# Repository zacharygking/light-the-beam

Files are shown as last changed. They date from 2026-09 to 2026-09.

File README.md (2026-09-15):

# Light the Beam

A 3D-printed Golden 1 Center that lights its purple beam when the Sacramento Kings win, with a live scoreboard in the base.



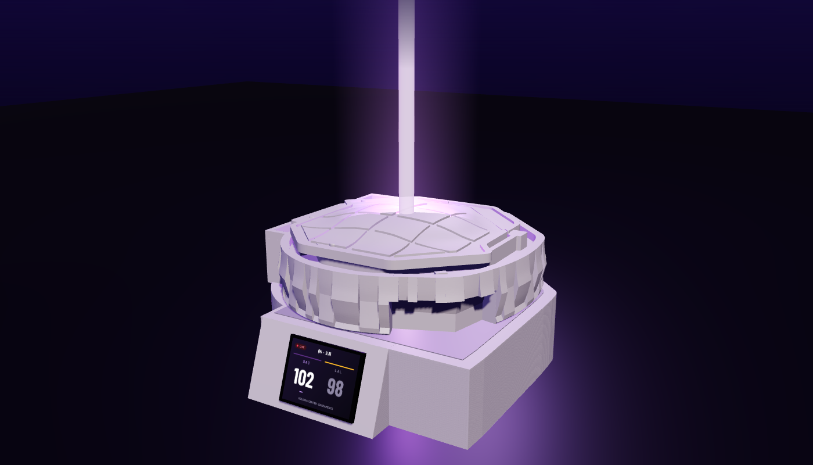
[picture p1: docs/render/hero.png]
The finished piece: the arena on its plinth, purple beam rising, live score on the screen


The arena base is [Dave Lack's free Printables model](https://www.printables.com/model/338758-golden-1-center-light-the-beam), printed unmodified (the lid gets one hole). Everything else is this repo: a printed plinth with a sloped console that holds a 2.8" ESP32 touch display, a 14-LED beam in a single-wall diffuser tube, firmware that reads ESPN's public scores over WiFi, and the documents to build it without soldering.

## What it does

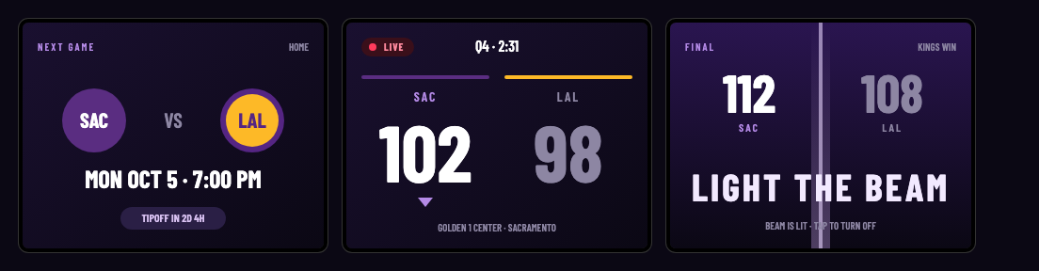
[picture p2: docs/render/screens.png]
The three screens: next game with logos and countdown, live score with clock, and the final screen that says Light the Beam


| | |
|---|---|
| **Next game** | Opponent logo, home or away, tipoff in Pacific time, countdown. Polled every 10 minutes, every 30 seconds near tipoff. |
| **Live** | Score, quarter and clock every 20 seconds. Leader in white, trailer in grey. Halftime and overtime are labelled; scores animate when they change. |
| **Final** | If the Kings win, the beam rises from the base like the real one and holds purple for up to 12 hours. |
| **Touch** | Tap to light the beam yourself. Hold for a second to step brightness. |
| **Setup** | First boot opens a `KingsBeam-Setup` WiFi network; join it from a phone and pick your home WiFi. Nothing is typed into code. |
| **Night** | Screen dims 11 pm to 7 am and whenever the room is dark. |

## How it's built

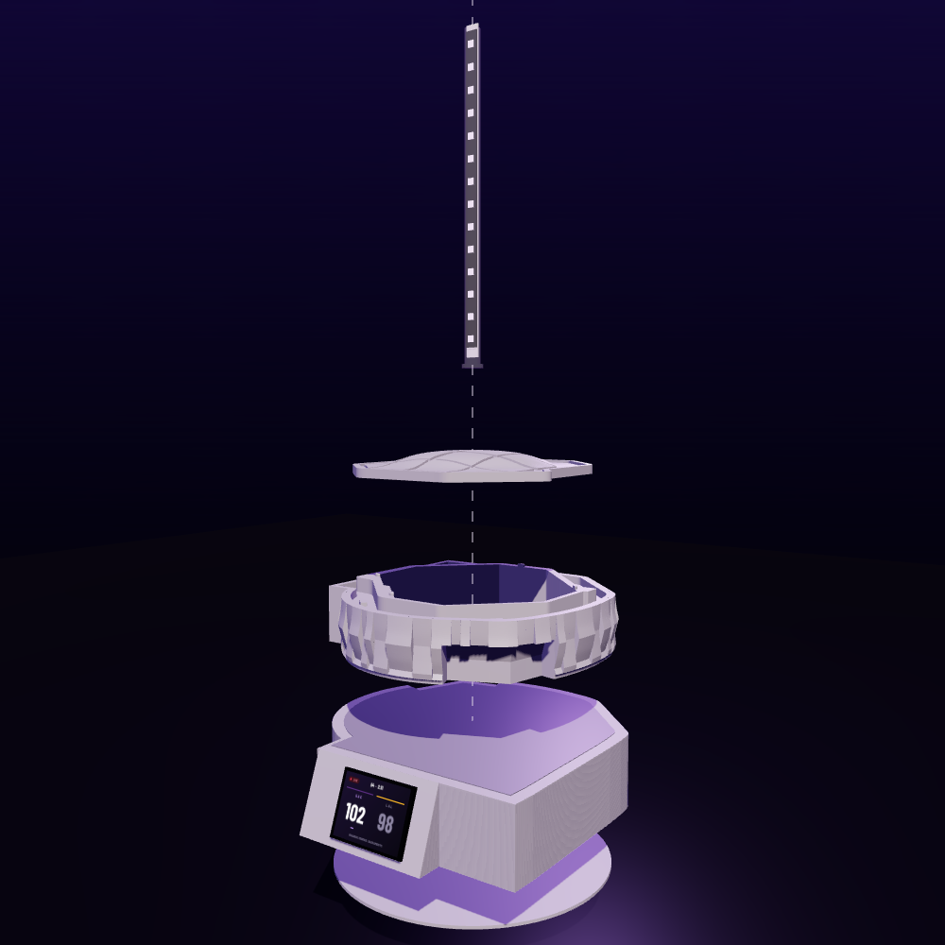
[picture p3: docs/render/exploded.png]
Exploded view: beam tube with the strip on its spine, arena lid, arena base with the tube socket, plinth with the display board, bottom lid


- **Plinth** ([`models/plinth.scad`](models/plinth.scad)): a 56 mm stand that follows the arena's measured footprint, with a console on the front whose face leans back 20° so the screen points at you at a desk. Three parts, each printable without supports: a wall ring with the console, a flat top plate whose recess is cut to the footprint (so the arena only fits one way) with a slot under the arena's own wire channel, and a bottom lid. The board slides up into the console with its USB plug attached; the lid closes the pocket.
- **Beam** ([`models/beam_tube.scad`](models/beam_tube.scad), [`models/strip_holder.scad`](models/strip_holder.scad)): a 250 mm tube printed in vase mode from white PLA, with the WS2812B strip on a printed spine inside and a socket glued in the arena's well.
- **Board**: ESP32-2432S028R, the "Cheap Yellow Display". Three lever-nut connections to the strip: 5 V, ground, data on GPIO 22.
- **Firmware** ([`firmware/`](firmware/)): PlatformIO, Arduino framework. LVGL 9 UI with Barlow Condensed fonts and all 30 team logos baked in, FastLED for the beam, WiFiManager for the captive portal, ArduinoJson with a filter for the 21 KB ESPN response. A `cyd_demo` build cycles the three screens without WiFi.

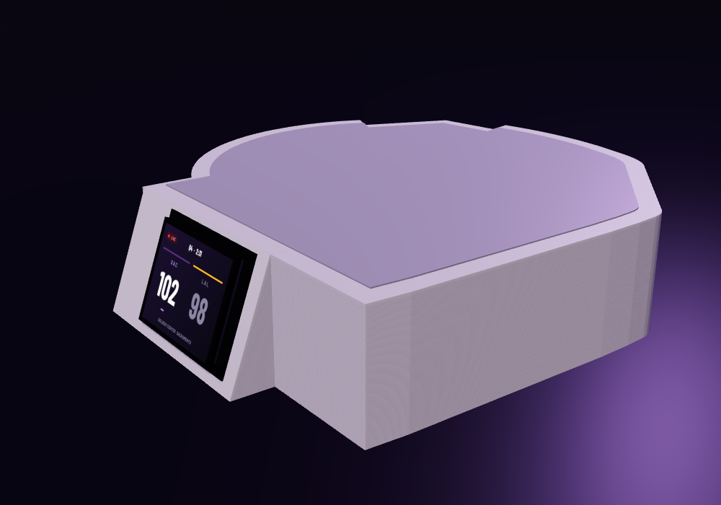
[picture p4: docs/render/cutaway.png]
Cutaway of the plinth: the display board leaning back in the console, lever nuts inside


## Documents

| | |
|---|---|
| [**Build guide** (PDF)](docs/kings-beam-assembly.pdf) | 15 pages, 22 steps with diagrams: print, flash, beam, arena and plinth, WiFi setup, troubleshooting. |
| [**Overview** (PDF)](docs/kings-beam-overview.pdf) | What it is and how it works, in five pages. |
| [**Shopping list** (PDF)](docs/kings-beam-shopping-list.pdf) · [HTML](docs/shopping-list.html) | Four hardware items in one Amazon cart link, filament, free downloads, local pickup in San Francisco. |
| [**Bill of materials**](docs/bom.md) | Sourcing notes, alternatives, prices with tax, wiring table. |

Hardware is about **$41 with tax**, everything bought new; filament is separate.

## Building it yourself

```sh
# Firmware (PlatformIO; `pip3 install --user platformio` if you don't have it)
cd firmware
pio test -e native                 # parser tests against captured ESPN responses
pio run -e cyd_demo -t upload      # demo build first: cycles NEXT → LIVE → FINAL, no WiFi
pio run -e cyd -t upload           # the real thing
pio device monitor -b 115200

# Models (OpenSCAD 2021.01 or newer)
python3 tools/measure_arena.py     # reads the downloaded arena STL, writes the footprint outline
cd models && make                  # exports plinth, lid, console test part, tube, spine, socket

# Everything at once
tools/validate.sh                  # tests, both firmware builds, exports, PDFs, link check
```

Print the console test part (`plinth_test.stl`, about 40 minutes) before the full plinth to confirm the board fit. The [build guide](docs/kings-beam-assembly.pdf) has the rest.

## Repository

| Path | What |
|---|---|
| `firmware/` | PlatformIO project: `src/` (UI, beam, touch, network, parser), `include/lv_conf.h`, `test/` (native Unity tests + real ESPN fixtures) |
| `models/` | OpenSCAD sources, `exports/` STLs, `printables/` for the downloaded arena files, `arena_outline.scad` (measured footprint) |
| `tools/` | `espn_probe.py`, `make_fixtures.py`, `check_fixtures.py`, `make_fonts.py` (TTF → LVGL, no Node needed), `make_logos.py`, `measure_arena.py`, `render_views.sh`, `validate.sh` |
| `docs/` | Guides and BOM, `render/` (three.js scene that renders every view through headless Chrome) |
| `.github/workflows/ci.yml` | Native tests, both ESP32 builds, generator reproducibility, OpenSCAD export |

## Notes from building it

- **ESPN's edge returns 403 to browser-looking user agents from non-browser clients.** The stock `ESP32HTTPClient` and `python-urllib` user agents pass. The firmware never spoofs a browser.
- ESPN's document nests 14 levels deep; ArduinoJson's default limit is 10. With a filter, ArduinoJson also reports success on non-JSON input, so the parser checks for the team object explicitly.
- The team endpoint omits opponent colours for upcoming games, so team colours ship with the logos.
- Fonts are converted from TTF to LVGL's bitmap format with a 150-line Python script, which keeps Node out of the toolchain.
- The renders are a three.js scene rasterised by headless Chrome's software WebGL. Once the Printables STL was downloaded, the scene loads the real mesh, and the same slicer measured the arena for the plinth.

## Status

Firmware builds and the parser is tested against real responses, but nothing has run on hardware yet. The three things most likely to need a tweak on first flash are display rotation, the touch pressure threshold, and the first LED's data level. The preseason opener is October 5, 2026 (LAL @ SAC); the live and final screens get their first real data then.

## Live win probability (v2, on the bench)

A four-coefficient logistic model of the home team's chance to win from the score, clock and period, the fields the firmware already polls, so it adds no requests. It was fitted on every play of the 2024-25 season and evaluated on every play of 2025-26, with ESPN's own in-game win probability recorded on the same plays as the benchmark:

| | Brier (lower is better) | log loss |
|---|---|---|
| this model | 0.162 | 0.476 |
| ESPN | 0.147 | 0.442 |
| home-court prior only | 0.247 | 0.687 |

The gap to ESPN is pregame information (team strength, possession): three Brier points in the first quarter, one thousandth by the fourth. Accuracy is 0.747 against ESPN's 0.778, but calibration is the number that matters for a probability pill, and league-wide it holds within three points in every bin. Restricted to Kings games it does not: the pill would have overstated a 22-win team's chances in toss-up situations, which is the case for adding a team-strength prior. Details, tables and open evaluation questions are in [docs/winprob.md](docs/winprob.md).

**The board trains itself.** The training plays are binned to 35,221 (margin, 5-second) cells with win/loss counts, a 247 KB table embedded in the firmware image. On boot the ESP32 refits the model from that table with `firmware/src/winprob_train.h`, a header-only Newton-Raphson trainer, and shows "TRAINED ON 623,853 PLAYS IN … MS" on the splash screen. It takes 23 ms on a laptop; the board's single-precision FPU should land well under a second.

**The bench is C++.** `firmware/src/winprob.h` is the exact function the ESP32 runs, and `pio test -e native` checks it against the Python trainer on 300 sampled plays, checks its shape (symmetry, monotonicity, end points), replays all 641,199 held-out plays through it asserting the Brier, fourth-quarter and calibration numbers above, and refits with the on-device trainer to confirm it reproduces the Python coefficients. It runs in CI. Data comes from `tools/fetch_pbp.py` (see [data/README.md](data/README.md)); `tools/train_winprob.py` refreshes the table, header, fixtures and report. Not wired to the live screen yet; that is a pill under the score once the hardware is up.

## Credits

Arena model by [Dave Lack](https://www.printables.com/@DaveLack_475585) on Printables. Scores from ESPN's public API. Team logos are NBA/ESPN property, embedded for personal use. Barlow Condensed by Jeremy Tribby, SIL Open Font License. Built with [PlatformIO](https://platformio.org), [LVGL](https://lvgl.io), [FastLED](https://fastled.io), [ArduinoJson](https://arduinojson.org), [WiFiManager](https://github.com/tzapu/WiFiManager), [OpenSCAD](https://openscad.org) and [three.js](https://threejs.org).

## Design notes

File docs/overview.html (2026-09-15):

Sacramento Kings · Golden 1 Center · Desk model

Render of the finished piece: the arena on its plinth, purple beam rising, live score on the screen

# LIGHT THE BEAM

A printed Golden 1 Center that lights its purple beam when the Kings win, with a live scoreboard in the base. WiFi, one USB cable, no soldering.

226 mmacross, on a Bambu P1S

2.8″ colortouch screen, LVGL UI

14 LEDsWS2812B beam, 250 mm tall

≈ $41hardware, tax in, new

Light the Beam · overviewSeptember 2026

What it does

## Features

### Next game, always up

Opponent logo, home or away, tipoff in Pacific time, and a countdown. Pulled from ESPN's public schedule; no account or API key.

### Live score and clock

Score, quarter and game clock refresh every 20 seconds during the game. The leader is drawn in white; the trailer fades to grey. Scores animate when they change.

### The beam lights itself on a win

When the final goes Kings, purple climbs the tube from the base, like the real one, then holds. It goes dark again before the next game.

### Light it yourself

Tap the screen to turn the beam on or off any time. Hold for a second to cycle brightness through three levels.

### Sleeps at night

The screen dims between 11 pm and 7 am, and whenever the board's light sensor sees a dark room.

### Phone WiFi setup

First boot puts up a "KingsBeam-Setup" network. Join it from a phone, pick your home WiFi, done. Nothing is typed into code.

### One cable, no soldering

A single USB charger powers the board and the beam. Three lever nuts join the strip to the board's pigtails.

### Stock arena, new plinth

Dave Lack's Printables arena base prints unmodified; the lid gets one 12.4 mm hole. A new printed plinth underneath holds the board, the screen window and the cable exit.

Light the Beam2

The 320 × 240 display

## Four screens

Next game. Logos on team-color discs, tipoff in local time, countdown pill. Polled every 10 minutes, every 30 seconds near tipoff.

Live. Pulsing pill, quarter and clock, team color bars, 84-pixel scores. Handles halftime, end of quarter and overtime.

Final, Kings win. A beam glow climbs the screen while the real one rises. On a loss: the score, "NEXT TIME", and a tap still lights it.

First boot. No credentials in code; the board runs a small setup page on its own network until it knows your WiFi.

Light the Beam3

Under the roof

## How it works

One request returns everything: the next event carries the date, opponent, status, score, clock and winner. The board only keeps the dozen fields it draws.

### Poll cadence

State | Every | Beam
Next game, far off | 10 min | off
Within 20 min of tipoff | 30 s | off
Live | 20 s | dim purple pulse
Final, Kings win | 5 min | rise, then hold up to 12 h
Final, loss | 5 min | off (tap still lights it)
ESPN unreachable | 60 s retry | unchanged, "offline" badge

### Things learned building it

ESPN's edge rejects browser-style user agents from non-browser clients with a 403, but accepts the ESP32 library's own default. The firmware never spoofs a browser.

The JSON nests fourteen levels deep. ArduinoJson's default limit is ten; the parser raises it and checks for the team object, since a filtered parse reports success on an HTML error page.

Fonts are converted from TTF to LVGL's bitmap format with a small Python script, so the build needs no Node toolchain.

Light the Beam4

Shopping and printing

## Parts and print list

Hardware | Price
ESP32-2432S028R 2.8″ touch display board (Amazon) | ~$14
WS2812B 5 V strip, 60/m, 1 m, IP30 (Amazon) | ~$9
5 V 2 A USB wall charger (Amazon or Best Buy) | ~$7
WAGO 221-413 lever nuts ×3 (Lowe's Bayshore or Amazon) | ~$8
SF sales tax 8.625 % | ~$3.30
Hardware total | ≈ $41

Optional: USB-C panel-mount jack for the back (~$9), level shifter if LED 1 flickers ($1.50). Prices are September 2026 estimates; links and local stores are in docs/bom.md.

Filament (P1S) | Price
Bambu PLA Basic Silver, 1 kg: arena, lid, plinth (~450 g) | $18.99
White PLA, any brand: beam tube, spine, socket (~35 g) | $13–19

Print | Settings | Time
Arena base, 220 mm | 0.2 mm, 3 walls, 15 %, no supports | ~9 h
Arena lid (no-hole, cut 12.4 mm) | 0.15 mm | ~2 h
Console test part | 0.2 mm | 40 min
Plinth ring, top plate, bottom lid | 0.2 mm, no supports | ~6 h
Beam tube, 254 mm | white, vase mode, 0 bottom layers | ~1 h
Spine + socket | any | 20 min

Exploded view: beam tube, arena lid, arena base, plinth, bottom lid

Top to bottom: beam tube with the strip on its spine, arena lid, arena base with the tube socket, plinth with the display board, press-fit bottom lid.

Light the Beam5

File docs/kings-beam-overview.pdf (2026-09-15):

SAC R A M ENTO K ING S · G O L D EN 1 C ENT E R · D E S K M O D E L

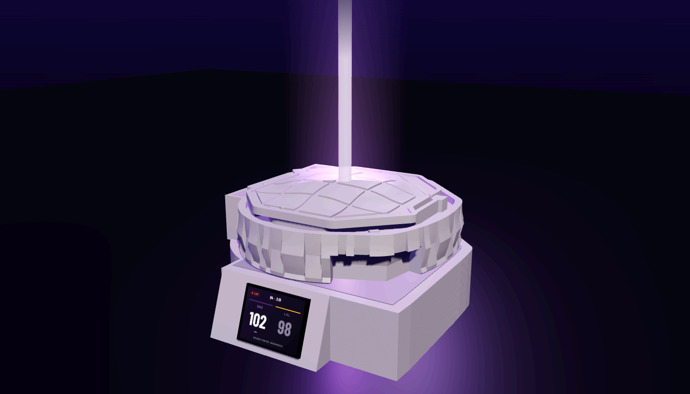
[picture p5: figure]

# LIGHT THE BEAM

## A printed Golden 1 Center that lights its purple beam when the

Kings win, with a live scoreboard in the base. WiFi, one USB cable, no soldering.

226 mm

across, on a Bambu P1S

# 2.8″ color

touch screen, LVGL UI

# 14 LEDs

WS2812B beam, 250 mm tall

≈ $41

hardware, tax in, new

Light the Beam · overview | September 2026

W H AT I T D O E S

# Features

## Next game, always up

Opponent logo, home or away, tipoff in Pacific time, and a countdown. Pulled from ESPN's public schedule; no account or API key.

## Live score and clock

Score, quarter and game clock refresh every 20 seconds during the game. The leader is drawn in white; the trailer fades to grey. Scores animate when they change.

## The beam lights itself on a win

When the final goes Kings, purple climbs the tube from the base, like the real one, then holds. It goes dark again before the next game.

## Light it yourself

Tap the screen to turn the beam on or off any time. Hold for a second to cycle brightness through three levels.

## Sleeps at night

The screen dims between 11 pm and 7 am, and whenever the board's light sensor sees a dark room.

## Phone WiFi setup

First boot puts up a "KingsBeam-Setup" network. Join it from a phone, pick your home WiFi, done. Nothing is typed into code.

## One cable, no soldering

A single USB charger powers the board and the beam. Three lever nuts join the strip to the board's pigtails.

## Stock arena, new plinth

Dave Lack's Printables arena base prints unmodified; the lid gets one 12.4 mm hole. A new printed plinth underneath holds the board, the screen window and the cable exit.

Light the Beam | 2

T H E 3 2 0 × 2 4 0 D I S P L AY

# Four screens

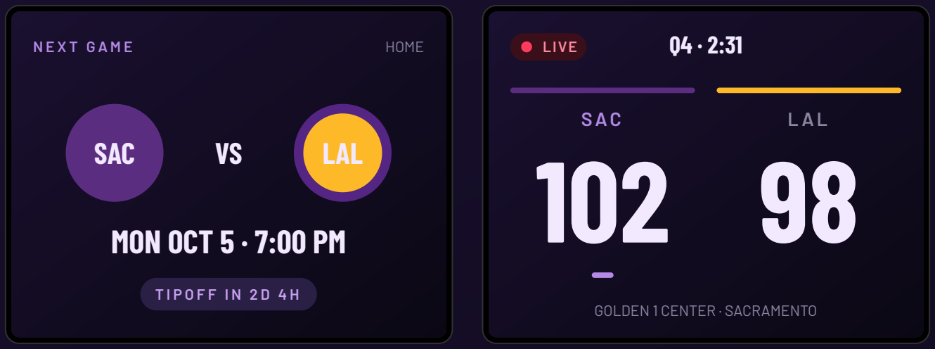
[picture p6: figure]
HOME; SAC; LAL; MON OCT 5 · 7:00 PM; LIVE; GOLDEN 1 CENTER · SACRAMENTO

Next game. Logos on team-color discs, tipoff in local time, countdown pill. Polled every 10 minutes, every 30 seconds near tipoff.

Live. Pulsing pill, quarter and clock, team color bars, 84-pixel scores. Handles halftime, end of quarter and overtime.

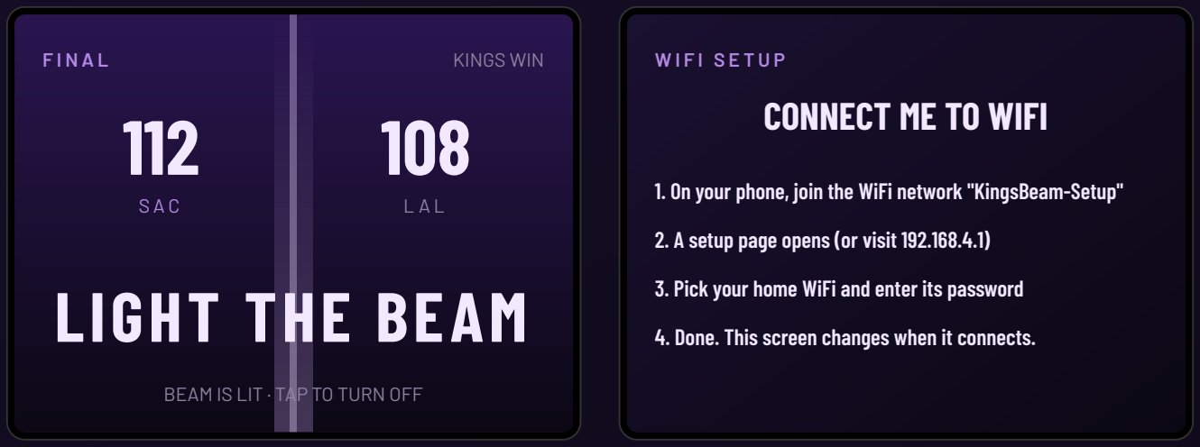
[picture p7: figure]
KINGS WIN; LIGHT THE BEAM; BEAM IS LIT · TAP TO TURN OFF; W I F I S E T U P CONNECT ME TO WIFI

Final, Kings win. A beam glow climbs the screen while the real one rises. On a loss: the score, "NEXT TIME", and a tap still lights it.

### 1. On your phone, join the WiFi network "KingsBeam-Setup"

### 2. A setup page opens (or visit 192.168.4.1)

### 3. Pick your home WiFi and enter its password

4. Done. This screen changes when it connects.

First boot. No credentials in code; the board runs a small setup page on its own network until it knows your WiFi.

UND E R T H E R O O F

# How it works

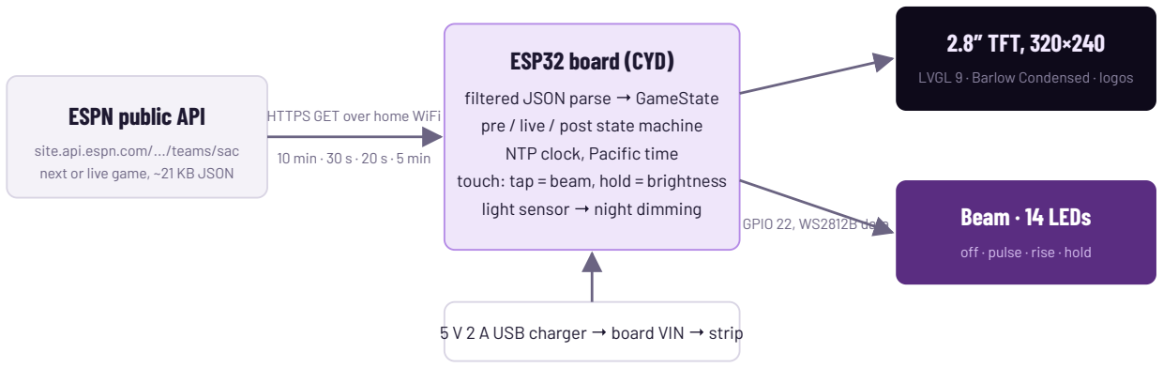
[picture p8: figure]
ESPN public API; site.api.espn.com/.../teams/sac next or live game, ~21 KB JSON; HTTPS GET over home WiFi; 10 min · 30 s · 20 s · 5 min; ESP32 board (CYD); filtered JSON parse → GameState pre / live / post state machine NTP clock, Pacific time touch: tap = beam, hold = brightness light sensor → night dimming; 2.8″ TFT, 320×240; LVGL 9 · Barlow Condensed · logos; GPIO 22, WS2812B data; Beam · 14 LEDs; off · pulse · rise · hold; 5 V 2 A USB charger → board VIN → strip

One request returns everything: the next event carries the date, opponent, status, score, clock and winner. The board only keeps the dozen fields it draws.

## Poll cadence

STATE | EVERY | BEAM
Next game, far off | 10 min | off
Within 20 min of tipoff | 30 s | off
Live | 20 s | dim purple pulse
Final, Kings win | 5 min | rise, then hold up to 12 h
Final, loss | 5 min | off (tap still lights it)
ESPN unreachable | 60 s retry | unchanged, "offline" badge

## Things learned building it

ESPN's edge rejects browser-style user agents from non-browser clients with a 403, but accepts the ESP32 library's own default. The firmware never spoofs a browser.

The JSON nests fourteen levels deep. ArduinoJson's default limit is ten; the parser raises it and checks for the team object, since a filtered parse reports success on an HTML error page.

Fonts are converted from TTF to LVGL's bitmap format with a small Python script, so the build needs no Node toolchain.

S H O P P ING AND P R INT ING

# Parts and print list

HARDWARE | PRICE
ESP32-2432S028R 2.8″ touch display board (Amazon) | ~$14
WS2812B 5 V strip, 60/m, 1 m, IP30 (Amazon) | ~$9
5 V 2 A USB wall charger (Amazon or Best Buy) | ~$7
WAGO 221-413 lever nuts ×3 (Lowe's Bayshore or Amazon) | ~$8
SF sales tax 8.625 % | ~$3.30
Hardware total | ≈ $41

Optional: USB-C panel-mount jack for the back (~$9), level shifter if LED 1 flickers ($1.50). Prices are September 2026 estimates; links and local stores are in docs/bom.md.

FILAMENT (P1S) | PRICE

Bambu PLA Basic Silver, 1 kg: arena, lid, plinth (~450

g) | $18.99
White PLA, any brand: beam tube, spine, socket (~35 g) | $13–19
PRINT | SETTINGS | TIME
Arena base, 220 mm | 0.2 mm, 3 walls, 15 %, no supports | ~9 h
Arena lid (no-hole, cut 12.4 mm) | 0.15 mm | ~2 h
Console test part | 0.2 mm | 40 min
Plinth ring, top plate, bottom lid | 0.2 mm, no supports | ~6 h
Beam tube, 254 mm | white, vase mode, 0 bottom layers | ~1 h
Spine + socket | any | 20 min

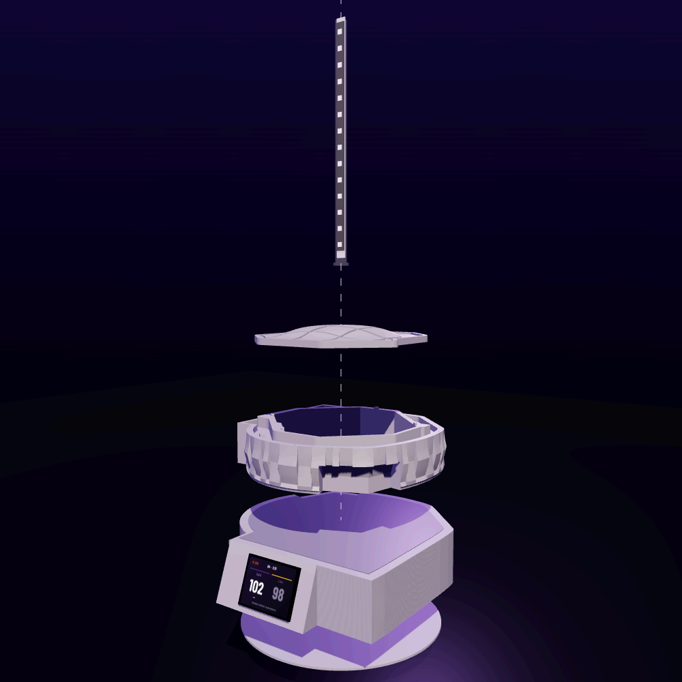
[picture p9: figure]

Top to bottom: beam tube with the strip on its spine, arena lid, arena base with the tube socket, plinth with the display board, press-fit bottom lid.

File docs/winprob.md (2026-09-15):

# Live win probability: model and bench

Fitted by `tools/train_winprob.py` on every play of the 2024-25 season (623,853 plays after dropping ESPN's in-feed scoring corrections, binned to 35,221 (margin, 5 s) cells with win/loss counts) and evaluated on every play of 2025-26 (641,199 plays, 1,322 games). ESPN's own in-game win probability, recorded on the same plays, is the benchmark.

## Model

```
f = fraction of regulation remaining, s = sqrt(f + eps), margin = home - away
logit P(home wins) = a + b_ms * margin / s + b_s * s + b_m * margin
```

| a | b_ms | b_s | b_m | eps |
|---|---|---|---|---|
| -0.0137 | 0.0956 | 0.1844 | -0.0111 | 0.005 |

Four coefficients in `firmware/src/winprob_coef.h`; inference is `winProbHome()` in `firmware/src/winprob.h`, one `expf` per poll.

## The board trains itself

The binned table (`firmware/data/winprob_train.bin`, 247 KB) is embedded in the firmware image, and `winProbTrain()` in `firmware/src/winprob_train.h` is the same Newton-Raphson fit as the Python trainer, header-only C++ with no dependencies. On boot the ESP32 refits the model from the table and reports the play count and time on the splash screen; the native bench (`test/test_winprob_train`) runs that exact code on the host and checks it lands on the coefficients above. The Python script is only needed to refresh the data.

## Held-out season 2025-26

| | plays | log loss | Brier | accuracy |
|---|---|---|---|---|
| this model | 641,199 | 0.4764 | 0.1617 | 0.747 |
| ESPN | 640,773 | 0.4418 | 0.1474 | 0.778 |
| home-court prior only | 641,199 | 0.6873 | 0.2471 | 0.556 |

Where the gap to ESPN comes from, by quarter (Brier, lower is better):

| quarter | plays | this model | ESPN | gap |
|---|---|---|---|---|
| 1st | 156,069 | 0.2289 | 0.1973 | +0.0315 |
| 2nd | 162,919 | 0.1918 | 0.1740 | +0.0178 |
| 3rd | 158,810 | 0.1455 | 0.1380 | +0.0075 |
| 4th + OT | 162,975 | 0.0833 | 0.0823 | +0.0010 |

ESPN's model also knows team strength (pregame odds) and who has the ball, which is worth about three Brier points in the first quarter and nothing by the fourth, when the scoreboard decides. The obvious next feature is a team-strength prior from the win-loss records; the pregame response carries neither team's record, so it would cost one extra request per game to the opponent's team endpoint.

Calibration of this model (predicted home win probability vs. how often the home team actually won):

| bin | plays | mean predicted | observed |
|---|---|---|---|
| 0.0–0.1 | 66,154 | 0.032 | 0.030 |
| 0.1–0.2 | 35,027 | 0.150 | 0.151 |
| 0.2–0.3 | 41,196 | 0.252 | 0.267 |
| 0.3–0.4 | 53,077 | 0.352 | 0.380 |
| 0.4–0.5 | 73,068 | 0.454 | 0.470 |
| 0.5–0.6 | 90,592 | 0.550 | 0.575 |
| 0.6–0.7 | 79,067 | 0.647 | 0.655 |
| 0.7–0.8 | 58,745 | 0.748 | 0.760 |
| 0.8–0.9 | 52,327 | 0.850 | 0.855 |
| 0.9–1.0 | 91,946 | 0.969 | 0.981 |

## Accuracy, and why it is not the headline

Accuracy here means: at every play, call the winner as whichever side is above 50%. It is easy to read but it scores a 51% and a 99% the same, so it cannot tell an honest 65% from an overconfident one. The pill's actual claim is "in situations like this one, the Kings win about this often", and the calibration table above is the test of that claim. Accuracy is reported for completeness:

| phase | plays | this model | ESPN | always pick home |
|---|---|---|---|---|
| tip-off | 1,339 | 0.557 | 0.688 | 0.558 |
| 1st quarter | 154,850 | 0.620 | 0.694 | 0.557 |
| 2nd | 163,030 | 0.702 | 0.733 | 0.555 |
| 3rd | 158,913 | 0.784 | 0.797 | 0.555 |
| 4th + OT | 163,067 | 0.880 | 0.883 | 0.555 |
| last minute | 22,934 | 0.939 | 0.939 | 0.551 |
| all plays | 641,199 | 0.747 | 0.778 | 0.556 |
| within 3 points, under 5 minutes | 17,575 | 0.716 | 0.715 | |
| SAC games only | 38,877 | 0.766 | 0.815 | |

At tip-off the model is exactly the always-home coin flip, because it knows nothing about the teams; ESPN's edge there is pregame odds. By the fourth quarter, and in close late-game situations, the two are indistinguishable. The SAC gap is wider than average for the same reason: a team's record is a strong pregame prior that ESPN has and this model does not.

## SAC games: what the pill would have shown

The pill shows P(SAC wins), so this restricts the held-out season to 82 SAC games (38,877 plays), flips the home probability when SAC is away, and calibrates that number (Brier 0.1524, log loss 0.4526). In toss-up situations (predicted 30–70%) the pill would have overstated SAC's chances by 19 points on average. That is systematic, not noise: SAC went 22-60, and the model starts every game at the league-average home prior. Late in games (the 0.8+ bins) the scoreboard takes over and the pill is honest again. This is the case for the team-strength prior below.

| bin | plays | mean predicted | SAC actually won |
|---|---|---|---|
| 0.0–0.1 | 8,174 | 0.029 | 0.020 |
| 0.1–0.2 | 3,762 | 0.150 | 0.090 |
| 0.2–0.3 | 4,104 | 0.250 | 0.173 |
| 0.3–0.4 | 4,675 | 0.352 | 0.181 |
| 0.4–0.5 | 5,350 | 0.450 | 0.253 |
| 0.5–0.6 | 4,663 | 0.547 | 0.341 |
| 0.6–0.7 | 3,072 | 0.644 | 0.449 |
| 0.7–0.8 | 1,747 | 0.749 | 0.653 |
| 0.8–0.9 | 1,649 | 0.848 | 0.834 |
| 0.9–1.0 | 1,681 | 0.960 | 0.992 |

## Not yet measured

- **Jitter between polls.** The board refreshes every 20 seconds, not every play. A replay at 20-second sampling would show how much the pill moves between refreshes, which is a display question rather than a model question, and decides whether the number needs smoothing or rounding to 5%.
- **A team-strength prior.** The SAC-only calibration above and the first two rows of the accuracy table are the same gap seen twice: the model starts every game at the league-average home prior. Win-loss records would recover most of it, at the cost of one extra request per game for the opponent's record (the pregame response carries neither team's). This is the first thing to add once the pill is on screen.

## C++ bench

`firmware/test/test_winprob` runs on the host with `pio test -e native -f test_winprob` (also in CI). It checks:

- the ESP32 inference reproduces the Python probability on 300 sampled plays (parity),
- symmetry, monotonicity and end-of-game behaviour of the function,
- the C++ trainer (`test/test_winprob_train`) refits from the embedded table and agrees with Python on every prediction within 0.001, and recovers known coefficients from synthetic data,
- a replay of the whole held-out season (641,199 plays in 1,322 games, `test/fixtures/winprob_eval.bin`, 5 bytes per play) through the firmware function. The C++ code must reproduce the table above: within 0.02 Brier of ESPN over the game and within 0.005 in the fourth quarter, at least 0.05 better than the home-court prior, and calibrated within 4 points in every bin.

Regenerate everything with `python3 tools/train_winprob.py` after refreshing `data/` (see `data/README.md`).

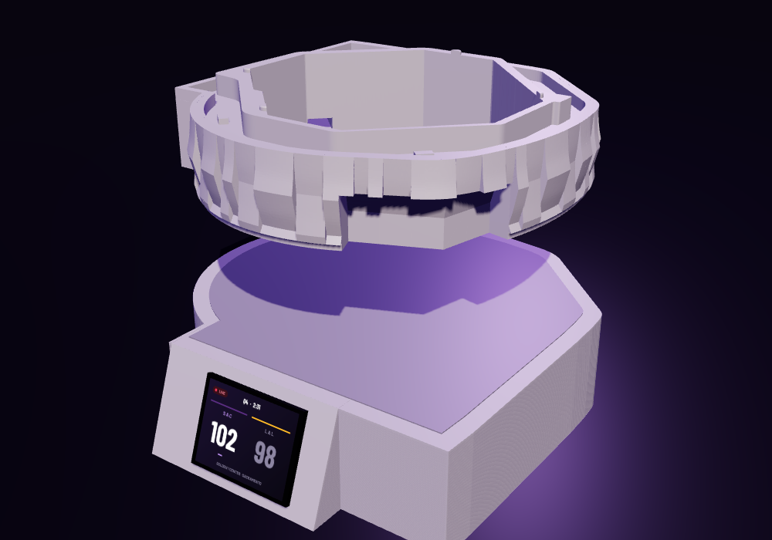
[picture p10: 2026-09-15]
docs/render/plinth_top.png

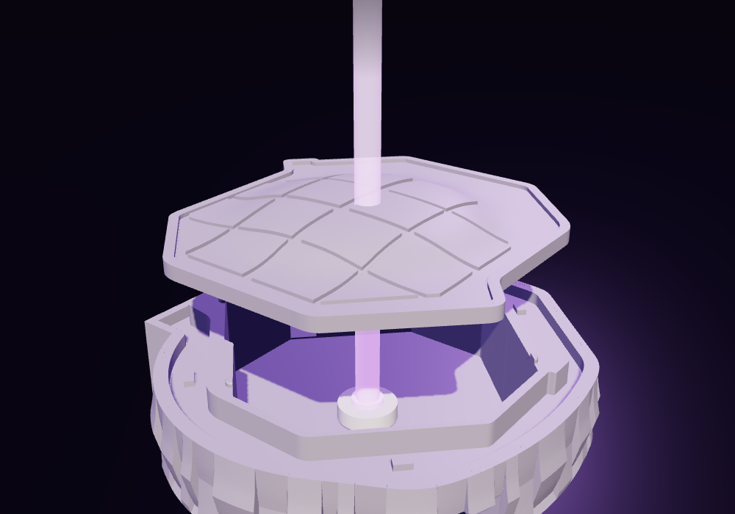
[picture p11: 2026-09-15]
docs/render/lid.png

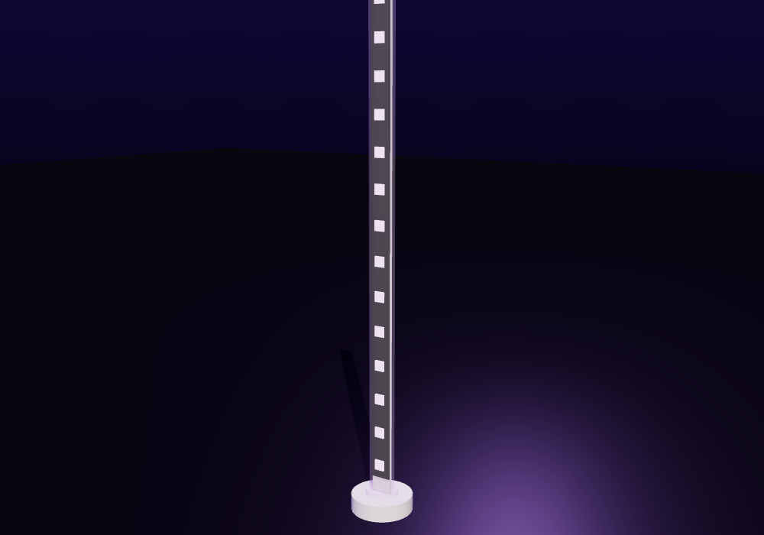
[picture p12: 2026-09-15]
docs/render/beam.png

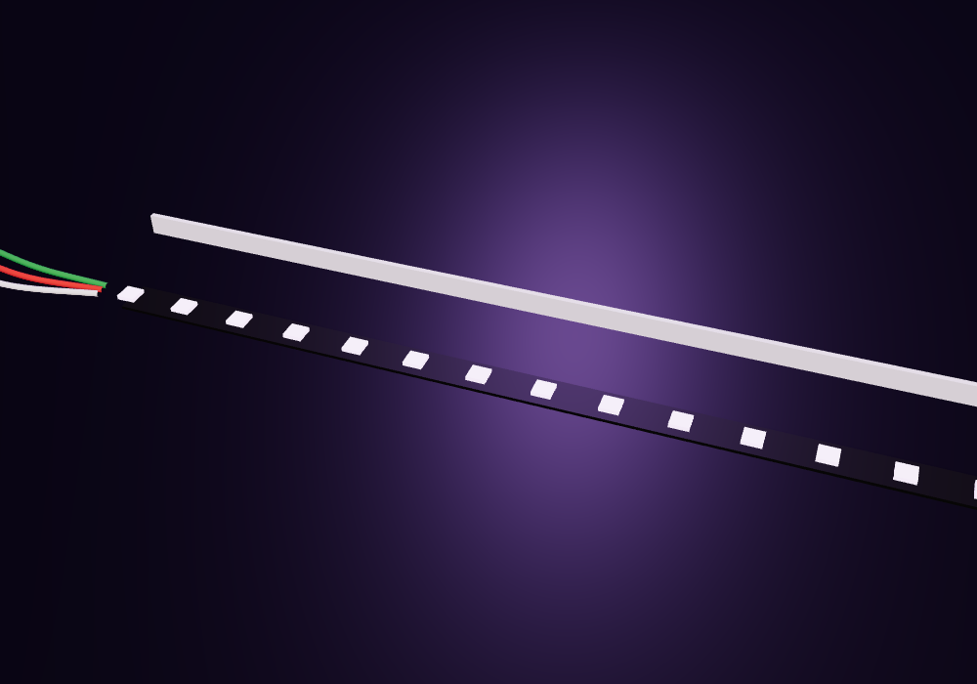
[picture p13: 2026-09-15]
docs/render/strip.png

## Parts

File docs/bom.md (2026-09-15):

# Bill of materials

Prices are September 2026, shipping to San Francisco (Bayview). SF sales tax is 8.625 % and
every seller below collects it. Items marked **verify** are typical Amazon prices that need a
live check at checkout; Adafruit and Bambu prices were read from their sites on 2026-09-14.

## Hardware: about $41 (with tax), everything new, solder-free

| # | Part | Exact item | Price | Where |
|---|---|---|---|---|
| 1 | ESP32 + 2.8" touch display | AITRIP 1-pack **ESP32-2432S028R** ("Cheap Yellow Display"). Ships with USB cable, JST pigtails, Dupont wires | ~$14 verify | [Amazon B0FCXDVBVZ](https://www.amazon.com/dp/B0FCXDVBVZ) |
| 2 | LED strip | BTF-LIGHTING **WS2812B 5 V, 60 LEDs/m, 1 m, IP30**, black PCB (white PCB: B01CDTE9UC). Bare 22 AWG leads on the ends | ~$9 verify | [Amazon B01CDTED80](https://www.amazon.com/dp/B01CDTED80) |
| 3 | 5 V / 2 A USB wall adapter | Amazon Basics 12 W one-port USB-A (2.4 A). Any 5 V 2 A+ charger works; the board's included cable is USB-A → micro-USB | ~$7 verify | [Amazon B0773J79KC](https://www.amazon.com/dp/B0773J79KC) or Best Buy Insignia 12 W ([SKU 6406429](https://www.bestbuy.com/site/6406429.p), ~$13) |
| 4 | Solder-free connectors | **WAGO 221-413** lever nuts (3-conductor, 24–12 AWG), pack of 10. Need 3 | ~$8 verify | [Amazon B06XGYXVXR](https://www.amazon.com/dp/B06XGYXVXR), Lowe's Bayshore (~$10), or [Home Depot 318072979](https://www.homedepot.com/p/318072979) |

| Scenario | Subtotal | Tax | Total |
|---|---|---|---|
| Items 1–4, all Amazon Prime ([one-click cart](shopping-list.html)) | $38 | $3.30 | **≈ $41** |
| Amazon board + strip, WAGO from Lowe's, charger from Best Buy | $46 | $4.00 | **≈ $50** |
| eBay board ($13.99) + AliExpress strip (~$4), 2–3 week wait | $33 | $2.85 | **≈ $36** |

### Optional

| Part | Exact item | Price | Where |
|---|---|---|---|
| USB-C panel-mount jack for the plinth back (cleaner than a cable slot) | AAOTOKK 1 ft USB-C M/F panel mount | ~$9 verify | [Amazon B08HS6X44P](https://www.amazon.com/dp/B08HS6X44P) |
| same, cheaper part, slower | Adafruit small round USB-C panel mount (12–18 mm hole) | $4.50 + ~$6 USPS | [Adafruit 6069](https://www.adafruit.com/product/6069) |
| Level shifter, only if the first LED flickers | Adafruit 74AHCT125 | $1.50 | [Adafruit 1787](https://www.adafruit.com/product/1787) |
| 2-pack of the display board (spare for another project) | ESP32-2432S028R 2-pack | ~$20 verify | [Amazon B0GX5X7BH6](https://www.amazon.com/dp/B0GX5X7BH6) |

Not needed: hookup wire (the board's pigtails reach the strip leads), soldering iron. A series
resistor on the data line is expected to be unnecessary with a 25 cm lead; add 300–500 Ω if LED 1
misbehaves (untested on hardware yet).

## Filament (separate; Bambu Lab P1S)

| Part | Exact item | Price | Where |
|---|---|---|---|
| Silver PLA, 1 kg — arena base + lid + plinth ring, top plate, bottom lid (~480 g) | Bambu PLA Basic Silver, with spool $18.99 / refill $15.99 | $16–19 | [Bambu US store](https://us.store.bambulab.com/products/pla-basic-filament) |
| White PLA — beam tube, spine and socket (~35 g; the tube is a single-wall vase print) | Bambu PLA Basic White refill, or ELEGOO / SUNLU white, or Bambu Jade White at Best Buy today ($22.99) | $13–23 | [Amazon search](https://www.amazon.com/s?k=white+pla+filament+1kg) |
| alt: one spool only | Print everything in white and skip the silver | $13–19 | — |
| optional accent | Bambu PLA Basic Purple for the plinth | $18.99 | Bambu store |

No clear PETG: a single 0.45 mm white PLA wall diffuses the strip well.

## Local pickup near Bayview

| Store | Distance | What | Notes |
|---|---|---|---|
| **Lowe's**, 491 Bayshore Blvd, SF 94124 · Mon–Sat 6a–10p, Sun 7a–8p · (415) 486-8611 | in the neighborhood | WAGO 221 lever nuts, USB chargers | Ask for the **221-413** (24–12 AWG); the site lists the bigger 221-613 |
| **Home Depot Colma II**, 2 Colma Blvd · same hours · (650) 755-9600 | ~6 mi | WAGO 221-413 10-pack (item 60338741) | backup for Lowe's |
| **Best Buy**, 1717 Harrison St, SF | ~3 mi | Insignia 12 W USB charger; Bambu PLA Basic (Jade White, Gray, Black) $22.99–24.99 | in-store pickup |
| **Central Computers**, 837 Howard St | ~4 mi | nothing useful (no ESP32 boards; PC ARGB strips at $35+) | skip |
| **Jameco**, 1355 Shoreway Rd, Belmont · will-call ≥ $20, 2 h processing | ~18 mi | Adafruit NeoPixel strips, Adafruit USB-C panel jack 4218 ($9.95) | no CYD board |
| **Micro Center**, 5201 Stevens Creek Blvd, Santa Clara | ~45 mi | Inland WS2812B 1 m strip, Inland PLA from $9.99, Bambu PLA, Inland ESP32 (no screen) | only if already down there |

**The display board is not stocked anywhere local.** Micro Center's WaveShare display boards
use a different driver and pinout. Order it on Amazon; Prime same-day / next-day covers SF.

## Wiring (solder-free)

```
CYD header P1  (VIN, TX, RX, GND)      CYD connector CN1 (GND, IO22, IO27, 3V3)
        VIN ──[WAGO]── strip 5V  (red)          IO22 ──[WAGO]── strip DIN (green)
        GND ──[WAGO]── strip GND (white/black)
```

- Use the JST pigtails that come with the board. Fold the thin pigtail wire back on itself so
  the WAGO clamps it; the strip's 22 AWG lead goes in the other port.
- 14 LEDs at the default brightness ≈ 0.45 A plus the board ≈ 0.2 A. The firmware caps the strip at
  0.9 A, so 1.1 A worst case: fine on a 2 A charger.
- 3.3 V data into a 5 V strip works with a short lead. If the first LED flickers, add the
  level shifter above.

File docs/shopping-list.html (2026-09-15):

# | Item | Where | Price
1 | ESP32 display board, ESP32-2432S028R2.8" touch screen "Cheap Yellow Display". Comes with the USB cable and the pigtail leads. Get the single-pack. | Amazon B0FCXDVBVZ (https://www.amazon.com/dp/B0FCXDVBVZ) | ~$14
2 | WS2812B LED strip, 5 V, 60 LEDs/m, 1 mBTF-LIGHTING, IP30 (no silicone sleeve), black PCB. You use 14 LEDs; the rest is spare. | Amazon B01CDTED80 (https://www.amazon.com/dp/B01CDTED80) | ~$9
3 | WAGO 221-413 lever nuts, 10-pack3-conductor, 24–12 AWG. You use 3. Also at Lowe's / Home Depot in the electrical aisle. | Amazon B06XGYXVXR (https://www.amazon.com/dp/B06XGYXVXR) | ~$8
4 | USB wall charger, 12 W (5 V 2.4 A)Amazon Basics one-port USB-A. Any 5 V 2 A+ charger works; the board's cable is USB-A → micro-USB. | Amazon B0773J79KC (https://www.amazon.com/dp/B0773J79KC) | ~$7
 | Sales tax, San Francisco 8.625 % |  | ~$3.30
 | Hardware total |  | ≈ $41
Item | Used for | Where | Price
Bambu PLA Basic, Silver, 1 kgwith spool $18.99 · refill $15.99 price read from store | arena base, lid, plinth ring, top plate, bottom lid (~480 g) | Bambu US store (https://us.store.bambulab.com/products/pla-basic-filament) | $18.99
White PLA, any brand, 1 kgBambu PLA Basic White refill $15.99, or ELEGOO / SUNLU ~$13, or Bambu Jade White at Best Buy today $22.99 | beam tube (single-wall vase print), spine, socket (~35 g) | Amazon (https://www.amazon.com/s?k=white+pla+filament+1kg) · Bambu store · Best Buy | $13–23
One-spool optionPrint everything in white and skip the silver. | all parts |  | $13–19
Item | Note | Where
Golden 1 Center arena files by Dave Lack220 mm base + 220 mm no-hole lid | Free Printables account needed to download | printables.com/model/338758 (https://www.printables.com/model/338758-golden-1-center-light-the-beam)
This project's firmware, plinth and beam partsOpenSCAD sources, STL exports, PlatformIO firmware, build guide | Open source | github.com/zacharygking/light-the-beam
Item | Why | Price
USB-C panel-mount jack, 1 ft (https://www.amazon.com/dp/B08HS6X44P) | Clean USB-C socket on the plinth's back instead of a cable slot | ~$9
74AHCT125 level shifter (https://www.adafruit.com/product/1787)Adafruit 1787 price read | Only if the first LED flickers | $1.50
Display board 2-pack (https://www.amazon.com/dp/B0GX5X7BH6) | A spare board for the next project, ~$5 more than one | ~$20
Store | Get | Note
Lowe's491 Bayshore Blvd · Mon–Sat 6a–10p, Sun 7a–8p | WAGO 221-413, USB charger | Ask for the 221-413 (24–12 AWG); the site lists the bigger 221-613
Best Buy1717 Harrison St | Insignia 12 W USB charger (~$13), Bambu PLA Basic ($22.99–24.99) | In-store pickup; White, Gray and Black usually stocked
Home Depot Colma II2 Colma Blvd | WAGO 221-413 10-pack | Backup for Lowe's

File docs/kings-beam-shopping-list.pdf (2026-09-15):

L I G H T T H E B EA M · SAC R A M ENTO K ING S D E S K M O D E L

# SHOPPING LIST

Everything to build one, with links. Four hardware items in one Amazon cart, filament from wherever you buy it, and the free arena files. Prices are September 2026 and change; the tax line assumes San Francisco (8.625 %).

Add all 4 hardware items to Amazon cart (https://www.amazon.com/gp/aws/cart/add.html?ASIN.1=B0FCXDVBVZ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)

Opens Amazon with the four items below added. If Amazon shows an error, use the individual links; they're the same products.

# Hardware · one Amazon order

# | ITEM | WHERE | PRICE

1 ESP32 display board, ESP32-2432S028R
2.8" touch screen "Cheap Yellow Display". Comes with the USB cable and the pigtail
leads. Get the single-pack.

Amazon
B0FCXDVBVZ (https://www.amazon.com/dp/B0FCXDVBVZ)

~$14

2 WS2812B LED strip, 5 V, 60 LEDs/m, 1 m
BTF-LIGHTING, IP30 (no silicone sleeve), black PCB. You use 14 LEDs; the rest is spare.

Amazon
B01CDTED80 (https://www.amazon.com/dp/B01CDTED80)

~$9

3 WAGO 221-413 lever nuts, 10-pack
3-conductor, 24–12 AWG. You use 3. Also at Lowe's / Home Depot in the electrical aisle.

Amazon
B06XGYXVXR (https://www.amazon.com/dp/B06XGYXVXR)

~$8

4 USB wall charger, 12 W (5 V 2.4 A)
Amazon Basics one-port USB-A. Any 5 V 2 A+ charger works; the board's cable is USB-A → micro-USB.

Amazon
B0773J79KC (https://www.amazon.com/dp/B0773J79KC)

~$7

Sales tax, San Francisco 8.625 % | ~$3.30
Hardware total | ≈ $41

Already have a 5 V 2 A phone charger and some lever nuts? Then it's just the board and the strip: about $25 with tax.

# Filament · Bambu Lab P1S

ITEM | USED FOR | WHERE | PRICE

Bambu PLA Basic, Silver, 1 kg
with spool $18.99 · refill $15.99
PRICE READ FROM STORE

arena base, lid, plinth ring, top plate, bottom lid (~480 g)

| | Bambu US store (https://us.store.bambulab.com/products/pla-basic-filament) | $18.99

White PLA, any brand, 1 kg
Bambu PLA Basic White refill $15.99, or ELEGOO / SUNLU ~$13, or Bambu Jade White at Best Buy today beam tube (single-wall vase print), spine, socket (~35 g)

Amazon (https://www.amazon.com/s?k=white+pla+filament+1kg) · Bambu
store · Best Buy

$13–23

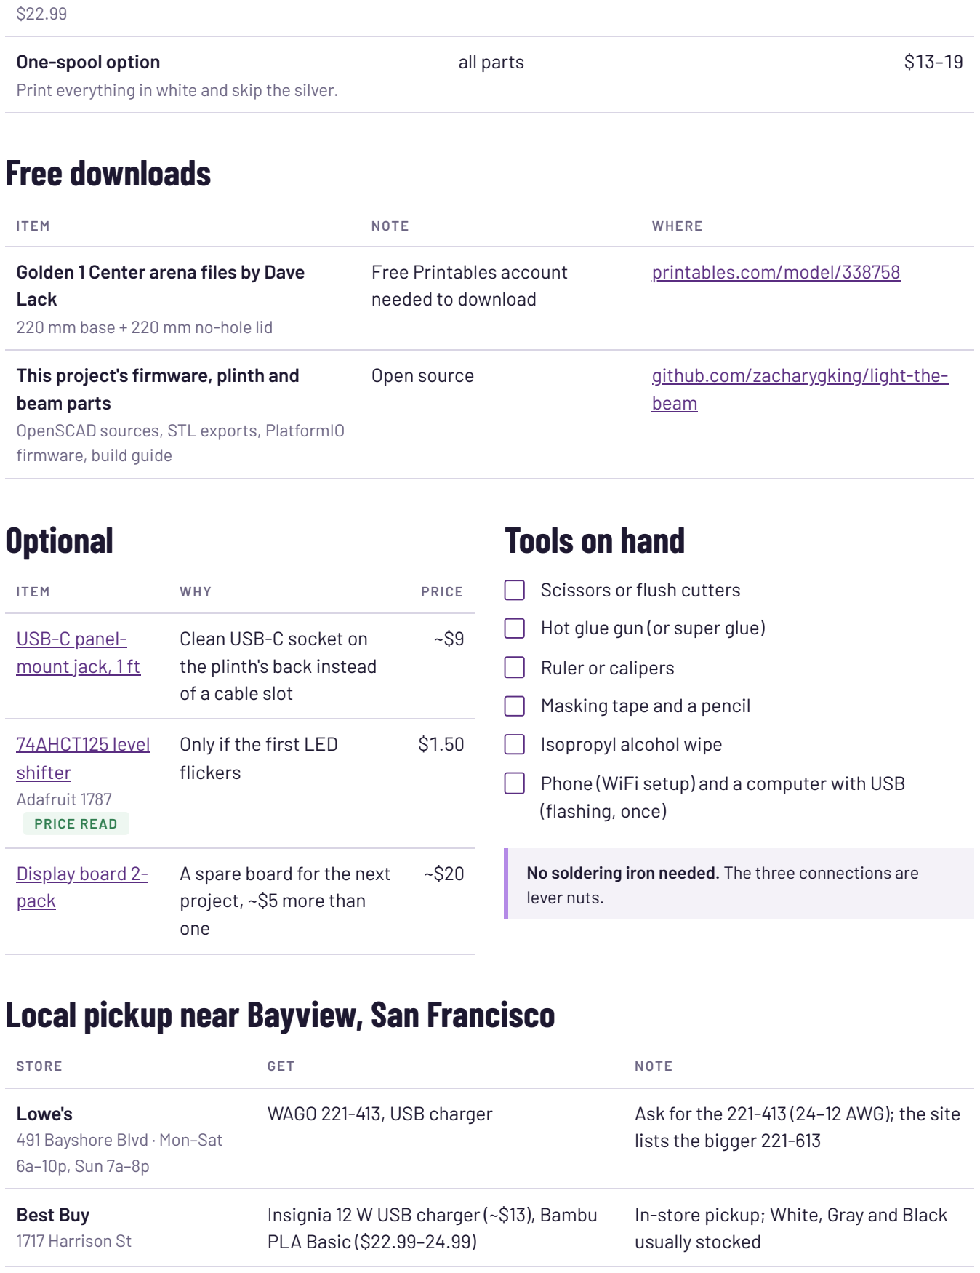
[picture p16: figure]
One-spool option; all parts; Free downloads; ITEM; NOTE; WHERE; Golden 1 Center arena files by Dave Lack 220 mm base + 220 mm no-hole lid; Free Printables account needed to download; printables.com/model/338758; This project's firmware, plinth and beam parts OpenSCAD sources, STL exports, PlatformIO firmware, build guide; Open source; github.com/zacharygking/light-the-; beam; Optional; WHY; PRICE; USB-C panel- mount jack, 1 ft; Clean USB-C socket on the plinth's back instead of a cable slot; 74AHCT125 level shifter Adafruit 1787; PRICE READ; Only if the first LED flickers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

Print everything in white and skip the silver.

No soldering iron needed. The three connections are

# Local pickup near Bayview, San Francisco

WAGO 221-413, USB charger | Ask for the 221-413 (24–12 AWG); the site

Phone (WiFi setup) and a computer with USB

Home Depot Colma II
2 Colma Blvd
WAGO 221-413 10-pack | Backup for Lowe's

The display board isn't stocked in any Bay Area store (Micro Center in Santa Clara carries different WaveShare boards that need other firmware). Order it on Amazon; Prime same-day / next-day covers SF.

Light the Beam · shopping list | Verified prices marked; others are September 2026 estimates. Full sourcing notes in docs/bom.md.

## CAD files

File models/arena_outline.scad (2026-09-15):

// Footprint of the 220 mm arena base at floor level, extracted from the Printables STL
// by tools/measure_arena.py. Centred on the footprint's bounding box. Units mm.
// The flat edge is at +X in this frame; plinth.scad rotates it so the flat edge faces the back (+Y).
arena_outline = [
  [102.91, -101.52],
  [102.91, -103.12],
  [85.61, -104.07],
  [-9.30, -104.01],
  [-26.29, -103.42],
  [-36.88, -102.50],
  [-39.42, -102.00],
  [-41.78, -101.19],
  [-43.24, -100.35],
  [-45.09, -98.82],
  [-92.20, -52.81],
  [-94.74, -49.47],
  [-96.76, -45.58],
  [-98.40, -40.88],
  [-99.45, -36.44],
  [-101.95, -20.19],
  [-102.57, -13.33],
  [-102.90, -4.68],
  [-102.82, 2.26],
  [-102.29, 10.88],
  [-101.28, 19.43],
  [-100.12, 26.31],
  [-98.66, 33.09],
  [-96.89, 39.81],
  [-85.66, 37.43],
  [-79.40, 67.00],
  [-38.85, 83.91],
  [-43.37, 94.54],
  [-39.74, 96.24],
  [-34.12, 98.52],
  [-28.33, 100.42],
  [-22.45, 101.93],
  [-16.48, 103.05],
  [-10.42, 103.76],
  [-4.39, 104.07],
  [5.83, 103.67],
  [11.85, 102.90],
  [17.78, 101.73],
  [23.64, 100.17],
  [29.59, 98.14],
  [35.72, 95.55],
  [39.81, 93.52],
  [43.89, 91.22],
  [49.57, 87.55],
  [54.96, 83.45],
  [58.51, 80.40],
  [63.45, 75.55],
  [67.93, 70.44],
  [72.07, 64.94],
  [74.62, 61.05],
  [76.94, 57.11],
  [79.98, 51.10],
  [102.91, 51.09],
  [102.91, -101.52]
];
arena_outline_size = [205.82, 208.16];
arena_well_offset = [1.51, -3.85];
arena_wire_exit = [102.9, -65.2];  // wall opening centre; spans y -75.5..-54.9

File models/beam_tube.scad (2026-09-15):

// Beam diffuser tube. Print in WHITE PLA in vase (spiralize) mode, 0.4 nozzle, ZERO bottom
// layers (the foot must stay open for the spine and wires) and a 5 mm brim for adhesion.
// The slicer turns this solid into a single-wall tube; the wall diffuses the LED strip inside.
//
//   openscad -o exports/beam_tube.stl beam_tube.scad
//
// The strip spine (strip_holder.scad) slides in from the bottom; the foot flange seats in the
// socket glued to the arena floor. The tip is a 30-degree cone ending in a 3 mm opening: vase
// mode cannot close a dome, and a cone this shallow prints cleanly.

tube_d   = 12;     // outer diameter; the lid hole should be tube_d + 0.4
tube_h   = 246;    // straight section; the cone tip adds 8 -> 254 total, under the P1S 256 mm Z
foot_d   = 16;
foot_h   = 3;

$fn = 96;

union() {
    cylinder(d = foot_d, h = foot_h);
    translate([0, 0, foot_h - 0.01]) cylinder(d1 = foot_d, d2 = tube_d, h = 2);
    translate([0, 0, foot_h + 2 - 0.02]) cylinder(d = tube_d, h = tube_h - foot_h - 2);
    // cone tip, 3 mm opening at the top
    translate([0, 0, tube_h - 0.01]) cylinder(d1 = tube_d, d2 = 3, h = 8);
}

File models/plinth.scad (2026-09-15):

// Plinth for the Golden 1 Center "Light the Beam" model.
//
// A low stand that follows the arena's footprint (offset outward by `margin`), with a sloped
// console on the front that holds the ESP32-2432S028R display board. The console face leans
// back 20° so the screen points up at someone at a desk, and nothing above blocks the view.
//
// Three printed parts, each printable without supports:
//   ring   the walls and the console, printed standing up (open top and bottom)
//   plate  the flat top: arena recess on top, wire slot, a rebate so it drops into the ring
//   lid    the bottom lid, with a tongue under the console
//
//   openscad -o exports/plinth.stl       -D part=\"ring\"  plinth.scad
//   openscad -o exports/plinth_top.stl   -D part=\"plate\" plinth.scad
//   openscad -o exports/plinth_lid.stl   -D part=\"lid\"   plinth.scad
//   openscad -o exports/plinth_test.stl  -D part=\"test\"  plinth.scad   <- console only, ~40 min
//
// The arena footprint comes from arena_outline.scad, written by tools/measure_arena.py from
// the downloaded 220 mm STL. Re-run that script if you print a different size.

include <arena_outline.scad>

part = "ring";            // "ring" | "plate" | "lid" | "test"

// ---- arena (from the measured STL) --------------------------------------------
arena_rot      = 90;      // rotate the measured outline so its flat edge faces the back (+Y)
arena_clear    = 0.8;     // gap around the arena in the recess (RDP chords + elephant's foot)
recess_depth   = 1.2;     // how deep the arena sits into the top plate
// rotate(90) maps (x, y) -> (-y, x): the measured wall opening becomes this point on the back
wire_exit      = [-arena_wire_exit[1], arena_wire_exit[0]];

// ---- plinth ------------------------------------------------------------------
margin         = 10;      // plinth outline = arena outline offset by this
plinth_h       = 56;      // overall height including the top plate
wall           = 3;
top_t          = 4;       // top plate thickness
rebate_h       = 3;       // the plate drops this far into the ring
lid_t          = 2.4;
lid_clear      = 0.3;
ring_h         = plinth_h - top_t + rebate_h;   // ring stands this tall; plate top ends at plinth_h

// ---- CYD board (ESP32-2432S028R) ----------------------------------------------
board_w        = 86.5;    // long axis (left-right in the console)
board_h        = 50.0;    // short axis (up the face)
board_stack    = 12;      // PCB + display module + connectors, pocket depth
usb_plug       = 16;      // room left of the board for the micro-USB plug body (cable attached before sliding in)
screen_w       = 62;      // window opening (active area is 57 x 43; +2.5 mm each side)
screen_h       = 47;
screen_ofs_x   = 7;       // active-area centre vs board centre along the long axis: MEASURE on the real board
screen_ofs_y   = 0;
pocket_clear   = 0.4;

// ---- console -----------------------------------------------------------------
tilt           = 20;      // face lean-back, degrees (0 = vertical)
pocket_w       = board_w + usb_plug + pocket_clear;       // board + plug, side by side
console_w      = pocket_w + 2 * wall;                     // ~108 mm
console_out    = plinth_h * tan(tilt);                    // bottom edge stands this far in front (~20 mm)
console_in     = 24;                                      // how far the console body reaches into the ring
front_y        = -arena_outline_size[0] / 2 - margin;     // y of the front-most point of the plinth outline (the prow)

// ---- cable exit --------------------------------------------------------------
usb_jack_d     = 0;       // 0 = plain cable slot; 18 = hole for a panel-mount USB-C jack
cable_slot_w   = 12;
cable_slot_h   = 8;

$fn = 96;
eps = 0.01;

// ---- outline helpers ---------------------------------------------------------
module footprint(r) { offset(r = r) rotate(arena_rot) polygon(arena_outline); }
module outline_solid(r, h) { linear_extrude(h) footprint(r); }

// ---- console -----------------------------------------------------------------
// Frame on the console face: origin at the face's bottom edge centre. Local +Z runs up the
// face; local +Y points INTO the console (the inward normal, tilted down by `tilt`); the
// window is cut toward local -Y, the pocket lives at local +Y.
module face_frame() {
    translate([0, front_y - console_out, 0]) rotate([-tilt, 0, 0]) children();
}
face_len = plinth_h / cos(tilt);
win_c    = face_len / 2;                          // window centre up the face
board_cx = usb_plug / 2;                          // board sits right of centre; plug room on the left

// Solid wedge on the front: face from (y = front_y - console_out, z = 0) to (y = front_y, z = plinth_h).
module console_solid() {
    rotate([90, 0, 90]) linear_extrude(height = console_w, center = true)
        polygon([[front_y + console_in, 0], [front_y - console_out, 0], [front_y, plinth_h], [front_y + console_in, plinth_h]]);
}

module window_cut() {
    face_frame() translate([board_cx + screen_ofs_x - screen_w / 2, -30, win_c - screen_h / 2 + screen_ofs_y])
        cube([screen_w, 30 + 2.2, screen_h]);
}

module pocket_cut() {
    // board + plug slide up into this from the open bottom; the 2.2 mm front lip holds the glass
    face_frame() translate([-pocket_w / 2, 2.2, -30])
        cube([pocket_w, board_stack, 30 + win_c + board_h / 2 + pocket_clear]);
    // connector relief behind the board (JST pigtails plug in from the back), inside the side walls
    face_frame() translate([-(console_w - 2 * wall) / 2, 2.2 + board_stack - 0.5, -30])
        cube([console_w - 2 * wall, 12, 30 + 16]);
}

// Hollow the console behind the connector relief, parallel to the face, inside the side walls,
// in front of a 3 mm back wall, below the top. Also opens the ring wall behind the console.
module console_hollow() {
    intersection() {
        face_frame() translate([-(console_w - 2 * wall) / 2, 2.2 + board_stack + 11.5, -1]) cube([console_w - 2 * wall, 80, 120]);
        translate([-console_w / 2, front_y - console_out - 1, -eps]) cube([console_w, console_out + console_in - wall + 1, ring_h - rebate_h]);
    }
}

module cable_exit() {
    back_y = arena_outline_size[0] / 2 + margin;   // flat back of the plinth outline
    if (usb_jack_d > 0)
        translate([0, back_y, plinth_h / 2 - 4]) rotate([90, 0, 0]) cylinder(d = usb_jack_d, h = 2 * wall + 2, center = true);
    else
        translate([-cable_slot_w / 2, back_y - wall - 1, -eps]) cube([cable_slot_w, wall + 2, cable_slot_h]);
}

module vents() {
    // two slots through each flank, well away from the console and the cable exit
    for (y = [-10, 30]) translate([-200, y - 1.5, 8]) cube([400, 3, 24]);
}

// ---- parts -------------------------------------------------------------------
module ring() {
    difference() {
        union() {
            outline_solid(margin, ring_h);
            console_solid();
        }
        // hollow, open top and bottom
        translate([0, 0, -eps]) outline_solid(margin - wall, ring_h + 2 * eps);
        // rebate at the top for the plate: thin the wall to half for the top rebate_h
        translate([0, 0, ring_h - rebate_h]) outline_solid(margin - wall / 2, rebate_h + eps);
        // lid rebate at the bottom
        translate([0, 0, -eps]) outline_solid(margin - wall / 2, lid_t + eps);
        window_cut();
        pocket_cut();
        console_hollow();
        cable_exit();
        vents();
    }
}

module plate() {
    difference() {
        union() {
            outline_solid(margin, top_t);                             // 0 .. top_t (printed flat)
            translate([0, 0, -rebate_h]) outline_solid(margin - wall / 2 - lid_clear, rebate_h + eps);   // drops into the ring
        }
        // arena locating recess on top
        translate([0, 0, top_t - recess_depth]) outline_solid(arena_clear, recess_depth + eps);
        // wire slot under the arena's wall opening, straddling the recess edge
        translate([wire_exit[0], wire_exit[1] + 1, -rebate_h - eps])
            hull() { for (dx = [-9, 9]) translate([dx, 0, 0]) cylinder(d = 6, h = rebate_h + top_t + 1); }
        // console top is part of the ring; notch the plate so it clears the console's back block
        translate([-console_w / 2 - eps, front_y - console_out - 1, -rebate_h - eps]) cube([console_w + 2 * eps, console_out + 1 + wall, rebate_h + eps]);
    }
}
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

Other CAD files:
models/strip_holder.scad

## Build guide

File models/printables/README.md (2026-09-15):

# Arena files from Printables

Download the 220 mm files from Dave Lack's model (free account needed) and drop them here:

https://www.printables.com/model/338758-golden-1-center-light-the-beam

- `G1C-Beam 220mm` **base**
- `G1C-Beam 220mm` **lid, no hole** (we cut our own 12.4 mm hole for the beam tube in Bambu Studio
  with a negative-part cylinder). The stock light-hole lid has a 14 × 34 mm slot for the author's
  light bar, not a round hole, so it is not a substitute.

These STLs are not committed to this repo (they're the author's work, licensed on Printables).

Name them `base_220.stl` and `lid_220_nohole.stl` here (the holed lid as `lid_220_hole.stl` if
you grabbed it too).

## Measure before printing the plinth

`python3 tools/measure_arena.py` from the repo root slices the base and writes
`models/arena_outline.scad`, which the plinth outline and its top-plate recess are cut to. What it found on the 220 mm file:

- footprint 205.8 × 208.2 mm, D-shaped: flat wall on one side, prow opposite
- solid floor about 1.5 mm thick, with an octagonal well ~165 mm across in the middle (the socket
  goes in its centre) and a solid deck around it
- a wire channel from the well to an opening in the flat wall 55–76 mm right of centre, 3–10 mm
  above the floor
- the lid seats on the inner box at 49.5 mm

Then `make` in `../` to export the STLs, and print `plinth_test.stl` first.

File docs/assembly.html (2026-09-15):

Sacramento Kings · Golden 1 Center · Model Kit

The finished model

# LIGHT THE BEAM

Build guide: printing, flashing, assembly and setup. Plan on two evenings: one for printing and flashing, one for assembly. No soldering.

Draft v0.2 · not yet built on hardware · read each part before starting it

Light the Beam · Build Guide · v0.2September 2026

Overview

## How this guide is organised

The build has five parts. Each part starts with what you need on the table and ends with a check so you know it worked before moving on. Times assume the prints are done.

Part 1 · Print the partsp. 3–4 · ~18 h printer time

Part 2 · Flash the boardp. 5 · 20 min

Part 3 · Build the beamp. 6–8 · 25 min

Part 4 · Arena and plinthp. 9–12 · 30 min

Part 5 · Power on and set upp. 13 · 10 min

Using it · Troubleshooting · Specsp. 14–15

### Parts list

Letters are used throughout the guide. Printed parts are A–G and L; bought parts are H–K (see docs/bom.md for links).

A

Arena base, 220 mmsilver PLA · Printables file

B

Arena lidsilver PLA · with 12.4 mm beam hole

C

Plinth ring + consolesilver PLA · plinth.stl

D

Plinth bottom lidsilver PLA · plinth_lid.stl

L

Plinth top platesilver PLA · plinth_top.stl · arena recess + wire slot

E

Beam tube, 250 mmwhite PLA · beam_tube.stl

F

Strip spinewhite PLA · beam_spine.stl

G

Tube socketwhite PLA · beam_socket.stl

H

Display boardESP32-2432S028R + USB cable + 2 pigtail leads

I

LED stripWS2812B 5 V, 60/m, 1 m · you use 14 LEDs

J

3 lever connectorsWAGO 221-413

K

USB power adapter5 V, 2 A or more, USB-A

—

OptionalUSB-C panel jack · 74AHCT125 level shifter

### Tools and supplies

Scissors or flush cutters

Hot glue gun (or super glue and patience)

Ruler or calipers

Small flat screwdriver (helps with the lever nuts)

Masking tape and a pencil

A phone and your home WiFi password

A computer with a USB port (for flashing, once)

Isopropyl alcohol wipe (for the socket glue joint)

Light the Beam2

Part 1 · Print the parts

## Get the files and measure the arena

1

### Download the arena from Printables

5 min

1. Open printables.com/model/338758 and sign in (a free account is required to download).
2. Click Download, then in the file list take only the two files for the 220 mm size: the base and the lid with no hole. Skip the 190 and 296 mm files and the pen-holder remix.
3. Save both into the project folder models/printables/.

Why the no-hole lid? The author's hole is sized for a store-bought light bar. Our beam tube is 12 mm, so you'll cut the hole yourself in step 5. If you'd rather not, download the holed lid too and measure it; if it's 12–13 mm it will work.

2

### Measure the base for the plinth

2 min

The plinth's recess is cut to the arena's exact footprint, so it needs the outline from the base file. A script reads it for you.

1. Rename the two downloaded files to base_220.stl and lid_220_nohole.stl inside models/printables/.
2. In Terminal, from the project folder, run python3 tools/measure_arena.py. It prints the footprint size, the floor thickness, where the wire channel exits, and writes models/arena_outline.scad.

python3 tools/measure_arena.py
# footprint 205.8 x 208.2 mm ... floor ~1.5 mm ... octagonal well 165 x 164 mm ... wire exit: opening in the flat wall ... lid seats at 49.5 mm
# wrote models/arena_outline.scad

The reported footprint is about 206 × 208 mm. If it's far off, you copied the wrong size file.

What's inside the arena. The floor is solid and about 1.5 mm thick. In the middle is an octagonal well about 165 mm across (the author hollowed it for a light bar; our socket goes in its centre). A wire channel already runs from that well to an opening in the flat back wall, 55–76 mm right of centre, 3–10 mm above the floor. The lid drops onto the inner box at 49.5 mm.

3

### Make the plinth, tube, spine and socket files

5 min

1. Install OpenSCAD if you don't have it (free, openscad.org, drag to Applications).
2. In Terminal: cd models && make. Seven STLs appear in models/exports/: the plinth ring, top plate, bottom lid and console test part, plus the tube, spine and socket.

cd ~/dev/personal/prints/sacramento_kings_beam/models
make            # writes exports/plinth.stl (ring), plinth_top.stl, plinth_lid.stl, plinth_test.stl, beam_tube.stl, beam_spine.stl, beam_socket.stl

Light the Beam3

Part 1 · Print the parts

## Slice and print

4

### Measure the board, then print the console test part

40 min print

1. Wait for board H to arrive. With a ruler, measure from the centre of the board's long edge to the centre of the picture area (the lit part, not the black border). On this board the picture sits toward the end away from the USB port, typically 6–9 mm off centre. Put that number in screen_ofs_x in models/plinth.scad (positive = toward the end away from the USB port) and run make again.
2. In Bambu Studio, import exports/plinth_test.stl. It's the console cut from the front of the plinth. Print it standing as exported (open side down), silver PLA, 0.2 mm, default walls, no supports.
3. When it's done, plug the micro-USB cable into the board, then slide board and plug together into the pocket from the open bottom, screen toward the window, plug on the left. It should slide with light finger pressure and stop with the glass against the window lip.
4. Look at it from the front. The picture area should be centred in the opening with an even margin.

Board slides in, screen centred, no rattle. If it's too tight, raise pocket_clear in plinth.scad by 0.2. If the picture is off to one side, change screen_ofs_x by the amount it's off (in mm; positive moves the window right). Re-run make and reprint only the test slice.

5

### Cut the beam hole in the lid

3 min

1. Import the no-hole lid. Right-click it → Add Negative Part → Cylinder.
2. In the negative part's settings set size 12.4 × 12.4 × 20 mm. Position it at the centre of the lid's inner raised panel (that's where the well below it is centred), sticking through the top and bottom.
3. Slice and confirm the preview shows a round hole through the lid.

12.4, not 12. The tube is 12 mm; the extra 0.4 is print tolerance so it slides without forcing.

6

### Print everything

~18 h printer time

Part | File | Filament | Orientation | Settings | Time
A · Arena base | Printables 220 base | silver | as downloaded, floor down | 0.2 mm · 3 walls · 15 % · no supports | ~9 h
B · Arena lid | Printables no-hole lid + your cut | silver | flat side down | 0.15 mm for the roof detail | ~2 h
C · Plinth ring + console | plinth.stl | silver | standing, as exported (open bottom on the plate) | 0.2 mm · 3 walls · no supports | ~4 h
L · Plinth top plate | plinth_top.stl | silver | flat, recess side up | 0.2 mm · 15 % gyroid | ~1 h 30
D · Bottom lid | plinth_lid.stl | silver | flat side down | 0.2 mm | ~40 min
E · Beam tube | beam_tube.stl | white | foot down | Spiral vase on · 0.4 nozzle · 0 bottom layers · 5 mm brim · 0.2 mm | ~1 h
F · Spine, G · Socket | beam_spine.stl, beam_socket.stl | white | spine flat, socket open side up | 0.2 mm | ~20 min

Vase mode for the tube only. In Bambu Studio: Process → Quality → Spiral vase, and set bottom shell layers to 0 so the foot stays open for the spine and wires. It prints one continuous wall, which is what makes the tube glow evenly. Don't enable it for anything else. The tip ends in a 3 mm opening; that's by design.

Plate layout. The base alone fills most of the plate. Print it on its own, then lid + spine + socket together, then the plinth ring on its own (it's 249 mm front to back, so no brim: use a skirt of 0), then the top plate with the bottom lid, then the tube on its own (a 254 mm vase print doesn't like neighbours).

Light the Beam4

Part 2 · Flash the board

## Put the firmware on the display board

Do this before assembly, while the board is easy to plug in. You only ever do it once; WiFi is set up from your phone later.

7

### Install PlatformIO (once)

5 min

1. Open Terminal and run the command below. It installs the build tool into your user folder; nothing system-wide changes.

python3 -m pip install --user platformio
export PATH="$HOME/Library/Python/3.9/bin:$PATH"     # use the path pip printed (3.12 on newer Macs); add to ~/.zshrc so it sticks

8

### Connect the board and flash the demo

5 min

1. Plug the board H into your Mac with its USB cable. Use the micro-USB port (some boards also have USB-C; either works for flashing).
2. In Terminal, go to the firmware folder and flash the demo build first. The first build downloads the ESP32 toolchain (a few hundred MB) and takes a few minutes.

cd ~/dev/personal/prints/sacramento_kings_beam/firmware
pio run -e cyd_demo -t upload
3. Watch the end of the output for SUCCESS. The board restarts by itself.

The screen lights up and cycles every 9 seconds: NEXT GAME (logos, countdown) → LIVE (big score) → FINAL · LIGHT THE BEAM. Tap the screen while the FINAL screen is up: the footer flips between "BEAM IS LIT" and "TAP TO LIGHT THE BEAM", which proves touch works even with no strip attached.

If the upload fails with "no serial port": unplug, plug back in, run again. If it still fails, hold the board's BOOT button while the upload starts, release after "Connecting…". If the picture is upside down or the colours are inverted, see Troubleshooting on page 15 and reflash.

9

### Flash the real firmware

3 min

pio run -e cyd -t upload

The screen shows the Kings logo, "STARTING", then "CONNECTING TO WIFI" for up to 20 seconds, then WIFI SETUP with four instructions. That's correct: it has no WiFi yet. Unplug the board; you'll set up WiFi in Part 5.

Want to watch it think? pio device monitor -b 115200 shows the log: WiFi, each ESPN fetch, and the beam decisions.

Light the Beam5

Part 3 · Build the beam

## Cut and mount the strip

10

### Cut the strip to 14 LEDs

5 min

1. Unroll the LED strip I. One end has three wires already attached (red, green, white or black) and usually a small white plug. That end stays.
2. Look closely at the strip: small arrows are printed along it. They point away from the wired end. Data travels in the arrow direction; the wired end is the input.
3. Starting at the wired end, count 14 LEDs. Put a piece of masking tape after the 14th.
4. Between LED 14 and LED 15 there is a set of three copper pads with a line through the middle. Cut exactly on that line with scissors, straight across.
5. Put the rest of the roll away; it's spare.

Cut on the line, not through an LED. Cutting anywhere else kills the LED on each side of the cut. If you slip, cut on the next line and live with 13 LEDs; set BEAM_NUM_LEDS in firmware/src/config.h to match.

Count 14 LEDs from the wired end. Cut on the pad line after the 14th, never through an LED.

11

### Stick the strip to the spine

5 min

1. Take spine F. It's a flat white bar with a small notch at one end. The notch is the bottom.
2. Wipe the spine with the alcohol wipe and let it dry; the strip's adhesive needs a clean surface.
3. Peel 3 cm of the strip's paper backing. Line the strip up on the flat face of the spine so the wired end is at the notch and the three wires exit through it.
4. Press down the first few LEDs, then peel and press a bit at a time along the length, keeping the strip straight and centred. It should end a little short of the top of the spine.
5. Rub the whole length down with a thumb.

Wires exit at the notched bottom, LEDs face away from the spine, strip runs straight to near the top.

Light the Beam6

Part 3 · Build the beam

## Into the tube, and a first light

12

### Slide the spine into the tube

3 min

1. Hold tube E with the wide foot flange down. The tube is open at the foot.
2. Feed the top of the spine (the end without wires) into the foot opening and push it up, LEDs facing the tube wall (any direction; it's round).
3. Push until the small feet at the bottom of the spine stop against the inside of the flange. The three wires should hang out of the foot.

Stuck halfway? The single-wall tube can be slightly oval. Rotate the spine 90° and try again, or gently squeeze the tube round. Never force it; the wall is 0.45 mm.

Optional: one small dab of hot glue where a spine foot meets the flange stops the spine sliding out when you tip the tube. Keep glue off the strip.

The spine goes in top-first through the foot opening; its feet stop against the inside of the flange.

13

### Test the beam before it goes inside the arena

5 min

It's much easier to fix a wiring mistake now than after the glue.

1. Find the two small pigtail leads that came with board H: thin cables with a tiny white plug on one end and bare tinned wires on the other. Plug one into the 4-pin socket labelled P1 (near the USB port) and one into CN1 (the 4-pin socket on the edge).
2. Identify the wires using the printed labels next to each socket. You need three: VIN and GND from P1, and IO22 from CN1. Put a bit of tape on each and write the name on it. Fold any unused wires back and tape them so they can't touch anything.
3. Open the three lever connectors J (flip the orange levers up). Make three joints, one per connector, matching the diagrams on the next page: VIN ↔ red, GND ↔ white/black, IO22 ↔ green. Push each bare wire in until it stops, then close the lever. The board's pigtail wires are thin: fold the bare end back on itself once so it's doubled before inserting.
4. Tug each wire gently. None should pull out.
5. Plug the board into the USB adapter K. It boots to WIFI SETUP. Tap the screen once.

The strip lights purple from the bottom LED up, then all 14 hold purple with a slow shimmer. Tap again: they go dark. Hold your finger on the screen for a second: brightness steps down; hold twice more: back to full.

Nothing lights? Unplug first. Check green is on IO22 (not IO27) and red is on VIN (not 3V3). Check the strip's arrows point away from the wired end. Only the first LED lights, or colours flicker? The data signal is marginal: shorten the green lead, or add the optional 74AHCT125 level shifter between IO22 and the strip.

Light the Beam7

Part 3 · Build the beam

## Wiring reference

Three wires, three connectors. This is the same for the bench test (step 13) and the final assembly (step 18).

Board pigtail | Strip wire | Carries | Connector
VIN (P1) | Red | 5 V power | J1
GND (P1) | White (or black) | Ground | J2
IO22 (CN1) | Green | Data | J3

The two pigtails plug into P1 and CN1. You use three of their wires: VIN, GND and IO22. Tape and label them.

One joint per connector: a board wire in one port, the matching strip wire in another. The third port stays empty.

Red goes to VIN, never to 3V3. 3V3 can't supply the strip and you'll get a dim, flickering beam. Green goes to IO22, not IO27 (they're neighbours on CN1). The unused wires on each pigtail (TX, RX, IO27, 3V3) get folded back and taped.

Light the Beam8

Part 4 · Arena and plinth

## Mount the beam in the arena

14

### Glue the socket to the arena floor

5 min + glue time

1. Unplug the board and open the three lever nuts to free the strip. Leave the taped board leads in place.
2. Take arena base A, lid off. In the middle of the floor is an octagonal well. Measure across it both ways with the ruler, mark the halfway points in pencil, and mark where the lines cross: that's the centre.
3. Wipe the floor there and the underside of socket G with the alcohol wipe.
4. Socket G has a slot in its side. Sit it dry on the mark with the slot facing the wire channel: the groove that leaves the well toward the flat back wall's right-hand corner. Draw round it with the pencil.
5. Lift it, run a ring of hot glue on its underside (or four dots of super glue), and press it back onto the pencil outline. Hold for 30 seconds. Super glue: leave it 10 minutes.

Centre and level matter. The tube is 250 mm tall, so a socket 2 mm off-centre puts the tube off-centre in the lid hole, and a socket glued on a blob of glue makes the beam lean. Press it flat.

15

### Stand the beam and route the wires

3 min

1. Pass the strip's three wires through the socket's slot, lay them in the wire channel, and push them out through its opening in the flat back wall (right-hand corner, just above the floor). Pull them through so there's no slack coiled in the well.
2. Lower the tube's foot flange into the socket. It should drop in with a little play and stand straight up.
3. Sight down from the front and from the side: the tube should be vertical. If it leans, the socket isn't flat; reheat the glue and reseat.

Tube stands straight, spins freely in the socket, wires exit the back of the arena with no strain on the strip.

Glue the socket in the centre of the well, slot toward the channel. Wires run along the channel and out the back-wall opening.

Light the Beam9

Part 4 · Arena and plinth

## Fit the lid

16

### Fit the lid

1 min

1. Hold lid B level above the arena, hole over the tube. Lower it straight down over the tube until its skirt drops inside the inner box and the flange rests on top of it.
2. Turn it until the small bump on the lid's edge lines up with the arena's back-right corner (it only sits flat one way).

The lid sits flat all round and the tube passes through the hole without touching its edge. If it touches, the socket is off-centre (step 14) or the hole isn't centred (step 5).

Keep the lid level as it goes on so the hole doesn't bind on the tube.

Light the Beam10

Part 4 · Arena and plinth

## How the screen mounts

The screen lives in a small sloped console on the front of the plinth. Its face leans back 20° so the picture points up at you at a desk, and because the console stands in front of the walls, nothing above it blocks the view. Inside the console is a pocket, open toward the bottom and wide enough for the board with its USB plug attached: board and plug slide up into it together, the window's lip stops the glass, and a tongue on the bottom lid closes the opening under the board. No screws.

17

### Seat the display board

5 min

1. Turn plinth C upside down, console toward you. The pocket opening is the rectangular slot in the underside of the console.
2. Unplug the two pigtails from board H so nothing snags. Plug the micro-USB cable into the board. Hold the board on its long edge, screen facing the sloped face, USB plug on the left; the pocket has 16 mm of extra room on that side for the plug.
3. Slide board and plug into the pocket together: light finger pressure, it stops when the glass meets the lip (same fit as step 4). Let the USB cable hang down out of the console.
4. Plug the pigtails back into P1 and CN1; they hang out of the open bottom.
5. Turn the plinth right side up and look at the console: picture centred in the window, even black margin. Turn it back over for wiring.

Loose? A folded strip of masking tape on the back of the board (never the screen) takes up slack. The bottom lid's tongue (step 19) closes the pocket so the board can't drop out.

Light the Beam11

Part 4 · Arena and plinth

## Connect the strip and close it up

18

### Make the three connections (for real this time)

5 min

Same three joints as the bench test in step 13 (wiring reference on page 8), now with the strip inside the arena and the board inside the plinth.

Board pigtail | Strip wire | Carries | Connector
VIN (P1) | Red | 5 V power | J1
GND (P1) | White (or black) | Ground | J2
IO22 (CN1) | Green | Data | J3

1. Drop top plate L into the ring C: recess up, its notch over the console, the wire slot at the back right. It sits in the ring's rebate flush with the top. Set the arena on the table behind the plinth, flat wall toward the plinth's back.
2. Feed the strip's three wires down through the slot in the plinth's top plate. It's at the back, right of centre, just outside the arena recess, directly under where the wires leave the arena wall.
3. Through the open bottom of the plinth, make the three lever-nut joints per the table. Fold the thin board wires double as before. Close each lever firmly; you'll feel it click.
4. Tug-test all six wire ends.

Red goes to VIN, never to 3V3. 3V3 can't supply the strip and you'll get a dim, flickering beam. Green goes to IO22, not IO27.

Strip wires: socket → wire hole → slot in the plinth top → lever nuts. Board USB cable → back slot.

19

### Route the cable and close the plinth

5 min

1. Tuck the three connectors into the plinth, toward the back, away from the board.
2. Route the board's USB cable (already plugged in) down through the console, across the inside of the plinth and out the slot at the back (or, if you fitted the optional panel jack, plug its short cable into the board instead and leave the jack's socket facing out).
3. Fit bottom lid D: its tongue goes forward under the console, finger hole toward the back, the USB cable through the notch in the tongue. Press it in evenly until it's flush; the tongue closes the pocket under the board.
4. Set the arena down onto the plate. The recess is cut to its exact D-shaped footprint, so it only fits one way: flat wall at the back. Make sure the strip wires drop into the slot and aren't pinched under the edge.

Plate flush in the ring, bottom lid flush, arena seated with no rocking, one cable out the back. Looking in the front window, the screen is centred and straight.

Light the Beam12

Part 5 · Power on and set up

## Join WiFi and light the beam

20

### Power on

1 min

1. Plug the USB cable into adapter K and the adapter into the wall.
2. The screen shows the Kings logo and STARTING, then CONNECTING TO WIFI for up to 20 seconds, then WIFI SETUP.

Use the 2 A adapter, not a laptop port. The beam plus the board can draw up to about 1 A; a laptop port may brown out and restart the board mid-animation.

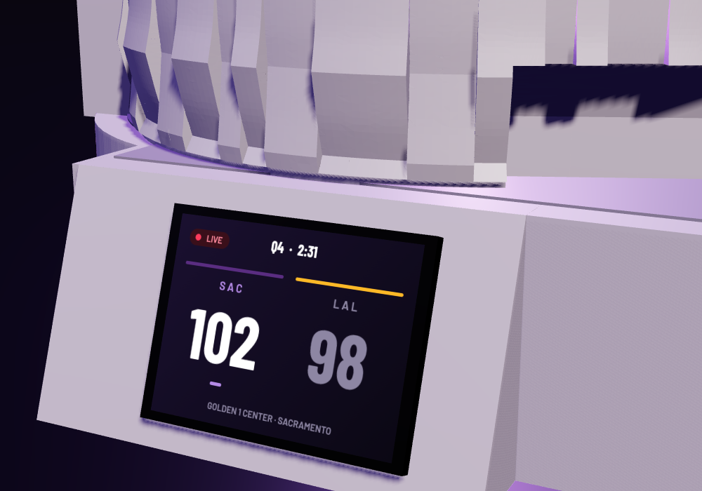
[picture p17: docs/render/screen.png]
The plinth with the screen lit


21

### Connect it to your home WiFi from your phone

3 min

1. On your phone, open Settings → WiFi. A new network called KingsBeam-Setup appears (it can take 20 seconds). Join it. There's no password.
2. A setup page pops up on its own, like a hotel login page. If nothing appears within 15 seconds, open the browser and type 192.168.4.1 in the address bar.
3. Tap Configure WiFi. The page lists nearby networks. Tap your home network. If it isn't listed, tap Refresh; the board only sees 2.4 GHz networks, so pick the 2.4 GHz name if your router has separate ones.
4. Type your WiFi password carefully (it's case-sensitive; tap the eye icon to check it) and tap Save.
5. The setup network disappears; your phone reconnects to your normal WiFi by itself. The board's screen shows CONNECTED and then, within about 10 seconds, NEXT GAME with the opponent and tipoff time.

Join the setup network, tap Configure WiFi, choose your home network, type the password, Save.

The NEXT GAME screen shows the right opponent and a sensible countdown. Time is synced from the internet, so the tipoff shown is already in Pacific time.

Wrong password? The board tries for 20 seconds, then opens KingsBeam-Setup again. Repeat this step from its first item. iPhone won't show the setup page? Turn off cellular data for a minute so the phone stays on the setup network, or use the address above.

22

### Light the beam

1 min

1. Tap the screen once. Purple climbs the tube from the base over two seconds and holds. Tap again to turn it off.
2. Hold a finger on the screen for a second to step the brightness (three levels).

Beam rises evenly with no dark LEDs. You're done. It will light itself the next time the Kings win.

Light the Beam13

Day to day

## Using it

### What the screen shows

Next gameOpponent logo, VS (home) or @ (away), tipoff in Pacific time, countdown pill. Refreshes every 10 minutes; every 30 seconds in the last 20 minutes before tipoff.

LiveScore, quarter and clock, refreshed every 20 seconds. Leader in white, trailer in grey with a marker under the leader. Halftime, end of quarter and overtime are labelled. The beam pulses softly.

Final, Kings winScore, "LIGHT THE BEAM", and the beam rises and holds.

Final, lossScore and "NEXT TIME". The beam stays off unless you tap it.

No game scheduledOff-season: the Kings logo and "NO GAME SCHEDULED".

OfflineA small OFFLINE badge in the corner. The last good screen stays; it retries every minute.

### Touch

TapBeam on / off, in any state.

Hold 1 sCycle beam brightness: low → medium → full.

### Automatic behaviour

After a winThe beam stays lit up to 12 hours, until you tap it off, or until the next game shows up on the schedule.

At nightScreen dims 11 pm–7 am, and whenever the room is dark (the board has a light sensor).

Power lossReboots into the current state in ~15 seconds; WiFi is remembered.

New WiFiIf it can't find the saved network for 20 seconds after boot, KingsBeam-Setup opens again. Repeat step 21.

### Care

Dust with a dry cloth. Keep out of direct sun and off radiators: PLA softens around 55 °C and the tube is thin. The lid lifts off to reach the beam; the bottom lid pulls off (finger hole) to reach the board. Unplug before opening.

Light the Beam14

If something's off

## Troubleshooting

Symptom | Try
Screen stays dark | Use the 2 A adapter, not a laptop. Try the board's other USB port if it has two. Check the cable is a data cable if you're flashing.
Colours inverted or milky | You have the other board variant. In firmware/platformio.ini, comment out ILI9341_2_DRIVER and enable the ST7789_DRIVER + TFT_INVERSION_ON lines noted there; reflash.
Picture upside down | In firmware/src/ui.cpp change LV_DISPLAY_ROTATION_90 to _270; reflash.
Screen off-centre in the window | Adjust screen_ofs_x / screen_ofs_y in models/plinth.scad by the offset in mm, make, reprint the console test part.
Beam never lights, even on tap | Unplug. Check red → VIN (not 3V3), green → IO22 (not IO27), white → GND. Check the strip's arrows point away from the wired end. Check each lever nut grips (tug test).
Only LED 1 lights / random colours | Data signal is marginal. Shorten the green lead to the minimum, or add the 74AHCT125 level shifter between IO22 and the strip's green wire.
Beam dim or flickers with the screen | Weak power. Use a 2 A adapter and a short USB cable. Step brightness down (hold 1 s) if it's a weak charger you can't change.
Beam leans | Socket not flat or off-centre: lift the lid, reheat the glue, reseat (step 14).
OFFLINE badge won't clear | ESPN unreachable from your network. It retries every minute. Check other devices have internet; reboot the board. If it persists for days, ESPN may have changed its edge rules; check python3 tools/espn_probe.py on your Mac.
Countdown wrong by hours | Clock not synced yet; wait a minute after connecting. If it stays wrong, your router blocks NTP (UDP 123).
Taps ignored | Press firmly with a fingertip in the middle of the screen; it's a resistive panel. Lower Z_THRESHOLD in firmware/src/touch.cpp if it never registers.
Setup network never appears | Power-cycle the board. It only opens the portal when it can't connect; if it already knows a WiFi and that WiFi is up, there's nothing to set up.

### Specifications

Footprint228 × 246 mm (plinth with console)

Height≈ 310 mm to the beam tip

Power5 V USB, ≈ 0.7 A with the beam lit, 1.1 A worst case, 0.3 A idle

Network2.4 GHz WiFi, outbound HTTPS and NTP only

DataESPN public scores; no account, nothing stored

BoardESP32-2432S028R, 2.8" 320 × 240 resistive touch

Beam14 × WS2812B in a 12 × 250 mm white PLA tube

### Safety

Low-voltage USB only; never connect to anything but a 5 V USB adapter. Indoor use. Unplug before opening the plinth or touching the wiring. The beam tube is thin-walled and not a toy. Printed PLA parts are not food-safe and should be kept away from heat.

### Files

Everything referenced here lives in the project repo: firmware/ (build and flash), models/ (OpenSCAD and STL exports), docs/bom.md (parts with links), tools/ (helper scripts).

Light the Beam15

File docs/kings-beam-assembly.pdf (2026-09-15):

SAC R A M ENTO K ING S · G O L D EN 1 C ENT E R · M O D E L K I T

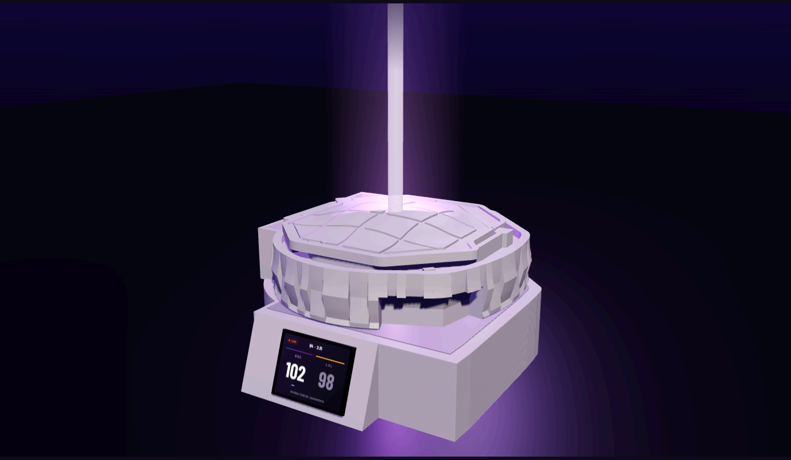
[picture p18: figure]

# LIGHT THE BEAM

### Build guide: printing, flashing, assembly and setup. Plan on two evenings: one for printing and flashing, one for assembly. No

soldering.

DRAFT V0.2 · NOT YET BUILT ON HARDWARE · READ EACH PART BEFORE STARTING IT

Light the Beam · Build Guide · v0.2 | September 2026

OVE RV I E W

# How this guide is organised

The build has five parts. Each part starts with what you need on the table and ends with a check so you know it worked before moving on. Times assume the prints are done.

Part 1 · Print the parts | p. 3–4 · ~18 h printer time | Part 2 · Flash the board | p. 5 · 20 min
Part 3 · Build the beam | p. 6–8 · 25 min | Part 4 · Arena and plinth | p. 9–12 · 30 min
Part 5 · Power on and set up | p. 13 · 10 min | Using it · Troubleshooting · Specs | p. 14–15

## Parts list

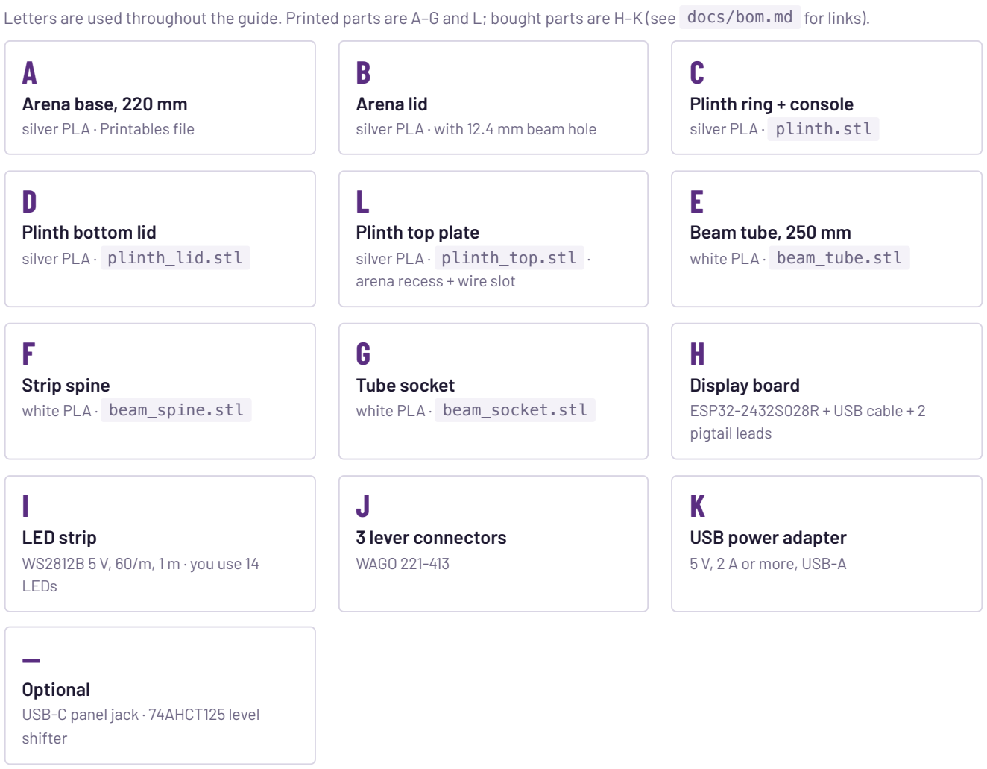
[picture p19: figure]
Arena base, 220 mm silver PLA · Printables file; Arena lid silver PLA · with 12.4 mm beam hole; Plinth ring + console silver PLA · plinth.stl; Plinth bottom lid; silver PLA · plinth_lid.stl; Plinth top plate; silver PLA · plinth_top.stl · arena recess + wire slot; Beam tube, 250 mm; white PLA · beam_tube.stl; Strip spine; white PLA · beam_spine.stl; Tube socket; white PLA · beam_socket.stl; Display board; ESP32-2432S028R + USB cable + 2 pigtail leads; LED strip; WS2812B 5 V, 60/m, 1 m · you use 14 LEDs; 3 lever connectors; WAGO 221-413; USB power adapter; 5 V, 2 A or more, USB-A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

Letters are used throughout the guide. Printed parts are A–G and L; bought parts are H–K (see docs/bom.md for links).

## Tools and supplies

✓ Scissors or flush cutters | ✓ Hot glue gun (or super glue and patience)
✓ Ruler or calipers | ✓ Small flat screwdriver (helps with the lever nuts)
✓ Masking tape and a pencil | ✓ A phone and your home WiFi password
✓ A computer with a USB port (for flashing, once) | ✓ Isopropyl alcohol wipe (for the socket glue joint)
Light the Beam | 2

PAR T 1 · P R INT T H E PAR T S

# Get the files and measure the arena

1 Download the arena from Printables | 5 MIN
1. Open printables.com/model/338758 and sign in (a free account is required to download).
2. Click Download, then in the file list take only the two files for the 220 mm size: the base and the lid with no hole. Skip the 190 and 296 mm files and the pen-holder remix.
3. Save both into the project folder models/printables/ .

Why the no-hole lid? The author's hole is sized for a store-bought light bar. Our beam tube is 12 mm, so you'll cut the hole yourself in
step 5. If you'd rather not, download the holed lid too and measure it; if it's 12–13 mm it will work.
2 Measure the base for the plinth | 2 MIN

The plinth's recess is cut to the arena's exact footprint, so it needs the outline from the base file. A script reads it for you.

1. Rename the two downloaded files to base_220.stl and lid_220_nohole.stl inside models/printables/ .
2. In Terminal, from the project folder, run python3 tools/measure_arena.py . It prints the footprint size, the floor thickness, where the wire channel exits, and writes models/arena_outline.scad .

python3 tools/measure_arena.py
# footprint 205.8 x 208.2 mm ... floor ~1.5 mm ... octagonal well 165 x 164 mm ... wire exit: opening in the flat wall ... lid seats at 49.5 mm

# wrote models/arena_outline.scad

CHECK The reported footprint is about 206 × 208 mm. If it's far off, you copied the wrong size file.

What's inside the arena. The floor is solid and about 1.5 mm thick. In the middle is an octagonal well about 165 mm across (the
author hollowed it for a light bar; our socket goes in its centre). A wire channel already runs from that well to an opening in the flat back wall, 55–76 mm right of centre, 3–10 mm above the floor. The lid drops onto the inner box at 49.5 mm.
3 Make the plinth, tube, spine and socket files | 5 MIN
1. Install OpenSCAD if you don't have it (free, openscad.org, drag to Applications).
2. In Terminal: cd models && make . Seven STLs appear in models/exports/ : the plinth ring, top plate, bottom lid and console test part, plus the tube, spine and socket.
make | # writes exports/plinth.stl (ring), plinth_top.stl, plinth_lid.stl,

PAR T 1 · P R INT T H E PAR T S

# Slice and print

4 Measure the board, then print the console test part | 40 MIN PRINT
1. Wait for board H to arrive. With a ruler, measure from the centre of the board's long edge to the centre of the picture area (the lit part, not the black border). On this board the picture sits toward the end away from the USB port, typically 6–9 mm off centre. Put that number in screen_ofs_x in models/plinth.scad (positive = toward the end away from the USB port) and run make again.
2. In Bambu Studio, import exports/plinth_test.stl . It's the console cut from the front of the plinth. Print it standing as exported (open side down), silver PLA, 0.2 mm, default walls, no supports.
3. When it's done, plug the micro-USB cable into the board, then slide board and plug together into the pocket from the open bottom, screen toward the window, plug on the left. It should slide with light finger pressure and stop with the glass against the window lip.
4. Look at it from the front. The picture area should be centred in the opening with an even margin.

CHECK Board slides in, screen centred, no rattle. If it's too tight, raise pocket_clear in plinth.scad by 0.2. If the picture is off to one side, change screen_ofs_x by the amount it's off (in mm; positive moves the window right). Re-run make and
5 Cut the beam hole in the lid | 3 MIN
1. Import the no-hole lid. Right-click it → Add Negative Part → Cylinder.
2. In the negative part's settings set size 12.4 × 12.4 × 20 mm. Position it at the centre of the lid's inner raised panel (that's where the well below it is centred), sticking through the top and bottom.
3. Slice and confirm the preview shows a round hole through the lid.

12.4, not 12. The tube is 12 mm; the extra 0.4 is print tolerance so it slides without forcing.
6 Print everything | ~18 H PRINTER TIME
PART | FILE | FILAMENT | ORIENTATION | SETTINGS | TIME
A · Arena
base
| Printables 220 base | silver | as downloaded, floor
down

0.2 mm · 3 walls · 15 % · no supports

~9 h

B · Arena lid | Printables no-hole lid + your | silver | flat side down | 0.15 mm for the roof detail | ~2 h

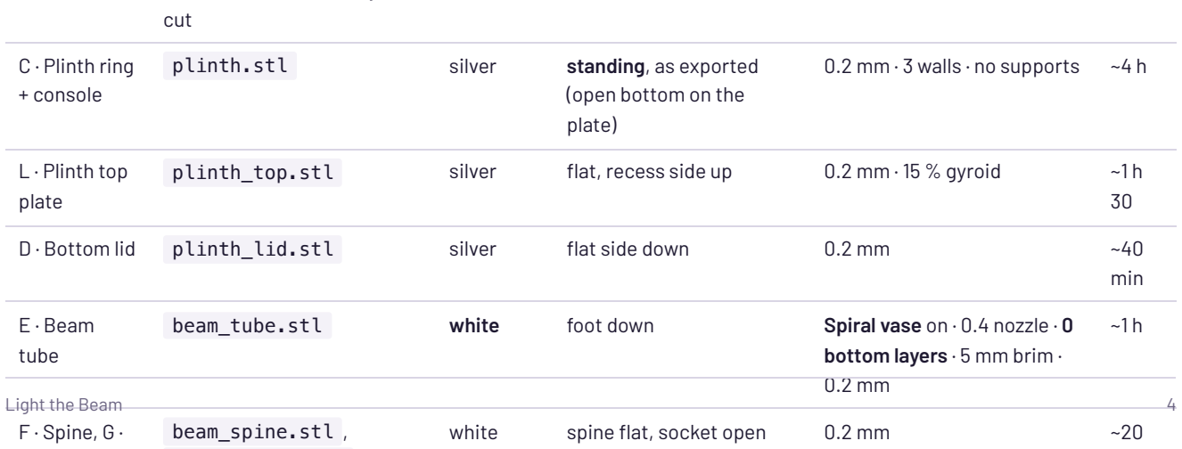
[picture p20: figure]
cut; C · Plinth ring + console; plinth.stl; silver; standing, as exported; (open bottom on the plate); 0.2 mm · 3 walls · no supports; L · Plinth top plate; D · Bottom lid; plinth_lid.stl; flat side down; min; E · Beam tube; bottom layers · 5 mm brim · 0.2 mm; F · Spine, G ·; beam_spine.stl ,; white; spine flat, socket open

plinth_top.stl | silver | flat, recess side up | 0.2 mm · 15 % gyroid | ~1 h
beam_tube.stl | white | foot down | Spiral vase on · 0.4 nozzle · 0

Socket
beam_socket.stl

side up

min

PAR T 2 · F L AS H T H E B OAR D

# Put the firmware on the display board

Do this before assembly, while the board is easy to plug in. You only ever do it once; WiFi is set up from your phone later.
7 Install PlatformIO (once) | 5 MIN
1. Open Terminal and run the command below. It installs the build tool into your user folder; nothing system-wide

python3 -m pip install --user platformio
export PATH="$HOME/Library/Python/3.9/bin:$PATH" | # use the path pip printed (3.12 on newer
8 Connect the board and flash the demo | 5 MIN
1. Plug the board H into your Mac with its USB cable. Use the micro-USB port (some boards also have USB-C; either works for flashing).
2. In Terminal, go to the firmware folder and flash the demo build first. The first build downloads the ESP32 toolchain (a few hundred MB) and takes a few minutes.
3. Watch the end of the output for SUCCESS . The board restarts by itself.

CHECK The screen lights up and cycles every 9 seconds: NEXT GAME (logos, countdown) → LIVE (big score) → FINAL · LIGHT THE BEAM. Tap the screen while the FINAL screen is up: the footer flips between "BEAM IS LIT" and "TAP TO LIGHT THE BEAM", which proves touch works even with no strip attached.

If the upload fails with "no serial port": unplug, plug back in, run again. If it still fails, hold the board's BOOT button while the upload starts, release after "Connecting…". If the picture is upside down or the colours are inverted, see Troubleshooting on page 15 and reflash.
9 Flash the real firmware | 3 MIN

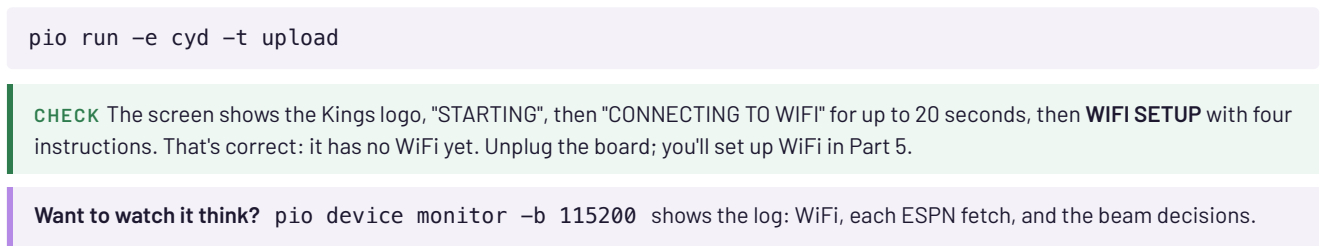
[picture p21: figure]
pio run -e cyd -t upload

CHECK The screen shows the Kings logo, "STARTING", then "CONNECTING TO WIFI" for up to 20 seconds, then WIFI SETUP with four instructions. That's correct: it has no WiFi yet. Unplug the board; you'll set up WiFi in Part 5.

Want to watch it think? pio device monitor -b 115200 shows the log: WiFi, each ESPN fetch, and the beam decisions.

PAR T 3 · B U I L D T H E B EA M

# Cut and mount the strip

10 Cut the strip to 14 LEDs | 5 MIN
1. Unroll the LED strip I. One end has three wires already attached (red, green, white or black) and usually a small white plug. That end stays.
2. Look closely at the strip: small arrows are printed along it. They point away from the wired end. Data travels in the arrow direction; the wired end is the input.
3. Starting at the wired end, count 14 LEDs. Put a piece of masking tape after the 14th.
4. Between LED 14 and LED 15 there is a set of three copper pads with a line through the middle. Cut exactly on that line with scissors, straight across.
5. Put the rest of the roll away; it's spare.

Cut on the line, not through an LED. Cutting anywhere else kills the LED on each side of the cut. If you slip, cut on the next line and live with 13 LEDs; set BEAM_NUM_LEDS in firmware/src/config.h to match.

CUT HERE
on the line through the copper pads,

wired end (input) — keep this end

arrows point away from the wires: 1 … 14

LED 1 | LED 14 15 (spare)
Count 14 LEDs from the wired end. Cut on the pad line after the 14th, never through an LED.

# 11 Stick the strip to the spine 5 MIN

1. Take spine F. It's a flat white bar with a small notch at one end. The notch is the bottom.
2. Wipe the spine with the alcohol wipe and let it dry; the strip's adhesive needs a clean surface.
3. Peel 3 cm of the strip's paper backing. Line the strip up on the flat face of the spine so the wired end is at the notch and the three wires exit through it.
4. Press down the first few LEDs, then peel and press a bit at a time along the length, keeping the strip straight and centred. It should end a little short of the top of the spine.
5. Rub the whole length down with a thumb.

CHECK Wires exit at the notched bottom, LEDs face away from the spine, strip runs straight to near the top.

top: ~10 mm bare spine

14 LEDs facing out

notch at the bottom
wires exit here

spine F

PAR T 3 · B U I L D T H E B EA M

# Into the tube, and a first light

# 12 Slide the spine into the tube 3 MIN

1. Hold tube E with the wide foot flange down. The tube is open at the foot.
2. Feed the top of the spine (the end without wires) into the foot opening and push it up, LEDs facing the tube wall (any direction; it's round).
3. Push until the small feet at the bottom of the spine stop against the inside of the flange. The three wires should hang out of the foot.

Stuck halfway? The single-wall tube can be slightly oval. Rotate the spine 90° and try again, or gently squeeze the tube round. Never force it; the wall is 0.45 mm.

Optional: one small dab of hot glue where a spine foot meets the flange stops the spine sliding out when you tip the tube. Keep glue off the strip.

tube E (section)
single 0.45 mm wall

slide up from the foot

feet stop here

LEDs face
the wall

The spine goes in top-first through the foot opening; its feet stop against the inside of the flange.
13 Test the beam before it goes inside the arena | 5 MIN

It's much easier to fix a wiring mistake now than after the glue.
1. Find the two small pigtail leads that came with board H: thin cables with a tiny white plug on one end and bare tinned wires on the other. Plug one into the 4-pin socket labelled P1 (near the USB port) and one into CN1 (the 4-pin socket on the edge).
2. Identify the wires using the printed labels next to each socket. You need three: VIN and GND from P1, and IO22 from CN1. Put a bit of tape on each and write the name on it. Fold any unused wires back and tape them so they can't touch anything.
3. Open the three lever connectors J (flip the orange levers up). Make three joints, one per connector, matching the diagrams on the next page: VIN ↔ red, GND ↔ white/black, IO22 ↔ green. Push each bare wire in until it stops, then close the lever. The board's pigtail wires are thin: fold the bare end back on itself once so it's doubled before inserting.
4. Tug each wire gently. None should pull out.
5. Plug the board into the USB adapter K. It boots to WIFI SETUP. Tap the screen once.

CHECK The strip lights purple from the bottom LED up, then all 14 hold purple with a slow shimmer. Tap again: they go dark. Hold your finger on the screen for a second: brightness steps down; hold twice more: back to full.

Nothing lights? Unplug first. Check green is on IO22 (not IO27) and red is on VIN (not 3V3). Check the strip's arrows point away from the wired end. Only the first LED lights, or colours flicker? The data signal is marginal: shorten the green lead, or add the optional 74AHCT125 level shifter between IO22 and the strip.

PAR T 3 · B U I L D T H E B EA M

# Wiring reference

Three wires, three connectors. This is the same for the bench test (step 13) and the final assembly (step 18).

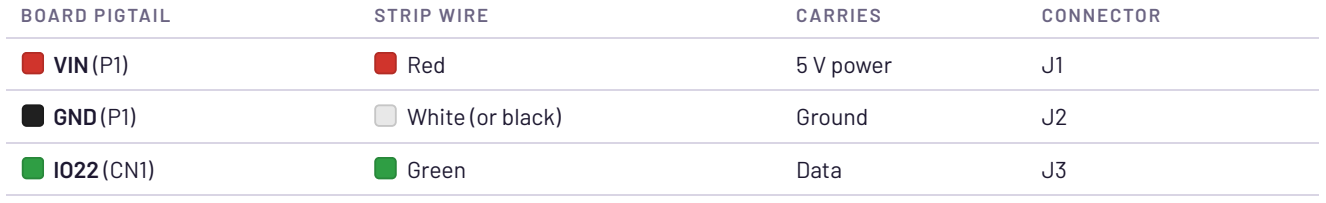
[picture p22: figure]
BOARD PIGTAIL; STRIP WIRE; CARRIES; CONNECTOR; VIN (P1); Red; 5 V power; GND (P1); White (or black); Ground; Green; Data
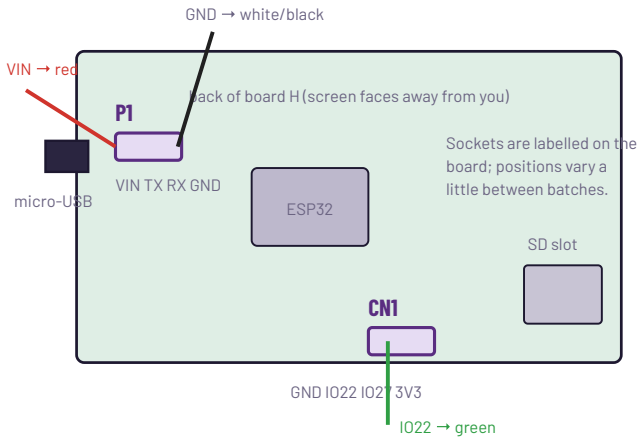
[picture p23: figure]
micro-USB; VIN TX RX GND; GND IO22 IO27 3V3; SD slot; ESP32; VIN → red; GND → white/black; IO22 → green; Sockets are labelled on the board; positions vary a little between batches.

back of board H (screen faces away from you)

The two pigtails plug into P1 and CN1. You use three of their wires: VIN, GND and IO22. Tape and label them.

1 LEVER UP | 2 PUSH TO THE STOP | 3 LEVER DOWN then tug: it must not move

Thin board wire: fold the bare end back on itself, then insert.

One joint per connector: a board wire in one port, the matching strip wire in another. The third port stays empty.

Red goes to VIN, never to 3V3. 3V3 can't supply the strip and you'll get a dim, flickering beam. Green goes to IO22, not IO27 (they're neighbours on CN1). The unused wires on each pigtail (TX, RX, IO27, 3V3) get folded back and taped.

PAR T 4 · AR ENA AND P L INT H

# Mount the beam in the arena

# 14 Glue the socket to the

# arena floor

### 5 MIN + GLUE

TIME
1. Unplug the board and open the three lever nuts to free the strip. Leave the taped board leads in place.
2. Take arena base A, lid off. In the middle of the floor is an octagonal well. Measure across it both ways with the ruler, mark the halfway points in pencil, and mark where the lines cross: that's the centre.
3. Wipe the floor there and the underside of socket G with the alcohol wipe.
4. Socket G has a slot in its side. Sit it dry on the mark with the slot facing the wire channel: the groove that leaves the well toward the flat back wall's right-hand corner. Draw round it with the pencil.
5. Lift it, run a ring of hot glue on its underside (or four dots of super glue), and press it back onto the pencil outline. Hold for 30 seconds. Super glue: leave it 10 minutes.

Centre and level matter. The tube is 250 mm tall, so a socket 2
mm off-centre puts the tube off-centre in the lid hole, and a socket glued on a blob of glue makes the beam lean. Press it flat.

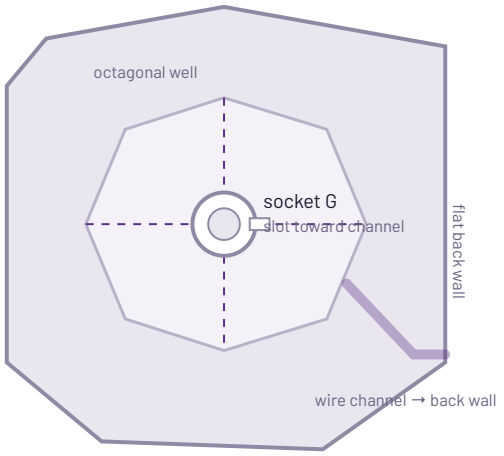
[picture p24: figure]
octagonal well; socket G slot toward channel; wire channel → back wall; flat back wall

arena A from above, lid off · front (prow) at the left

# 15 Stand the beam and route the

# wires

3
MIN
1. Pass the strip's three wires through the socket's slot, lay them in the wire channel, and push them out through its opening in the flat back wall (right-hand corner, just above the floor). Pull them through so there's no slack coiled in the well.
2. Lower the tube's foot flange into the socket. It should drop in with a little play and stand straight up.
3. Sight down from the front and from the side: the tube should be vertical. If it leans, the socket isn't flat; reheat the glue and reseat.

CHECK Tube stands straight, spins freely in the socket, wires exit the back of the arena with no strain on the strip.

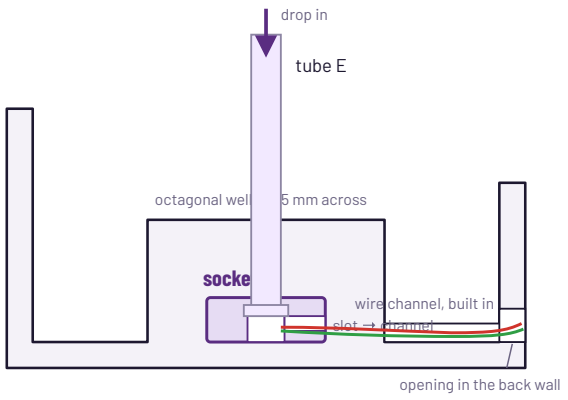
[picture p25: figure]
wire channel, built in; opening in the back wall; octagonal well, ~165 mm across; socket G; slot → channel; tube E; drop in

arena A, front on the left, flat back wall on the right
Glue the socket in the centre of the well, slot toward the channel. Wires run along the channel and out the back-wall opening.

PAR T 4 · AR ENA AND P L INT H

# Fit the lid

16 Fit the lid | 1 MIN
1. Hold lid B level above the arena, hole over the tube. Lower it straight down over the tube until its skirt drops inside the inner box and the flange rests on top of it.
2. Turn it until the small bump on the lid's edge lines up with the arena's back-right corner (it only sits flat one way).

CHECK The lid sits flat all round and the tube passes through the hole without touching its edge. If it touches, the socket is off-centre (step 14) or the hole isn't centred (step 5).

lid B, hole 12.4 mm

lower straight down, keep it level

tube E

arena A

rim

Keep the lid level as it goes on so the hole doesn't bind on the tube.

PAR T 4 · AR ENA AND P L INT H

# How the screen mounts

The screen lives in a small sloped console on the front of the plinth. Its face leans back 20° so the picture points up at you at a desk, and because the console stands in front of the walls, nothing above it blocks the view. Inside the console is a pocket, open toward the bottom and wide enough for the board with its USB plug attached: board and plug slide up into it together, the window's lip stops the glass, and a tongue on the bottom lid closes the opening under the board. No screws.

### FRONT

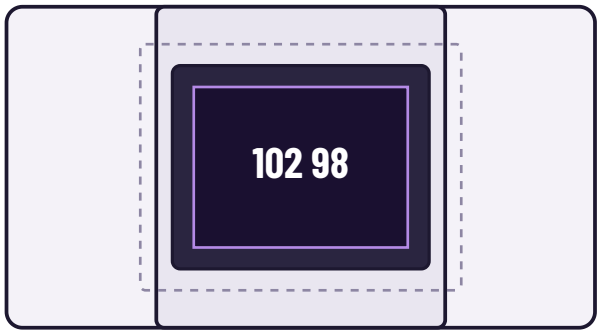
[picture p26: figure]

console 96 mm wide · window 60 × 46 · dashed: board inside picture area centred in the window

### SIDE, CUT THROUGH

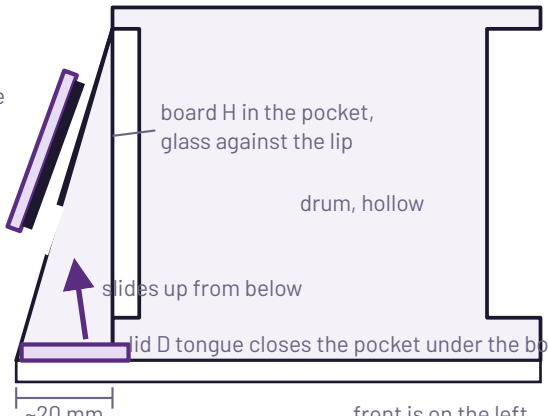
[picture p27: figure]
board H in the pocket, glass against the lip; slides up from below; drum, hollow

face
20°

lid D tongue closes the pocket under the board

~20 mm | front is on the left

### BOTTOM, PLINTH UPSIDE DOWN

17 Seat the display board | 5 MIN

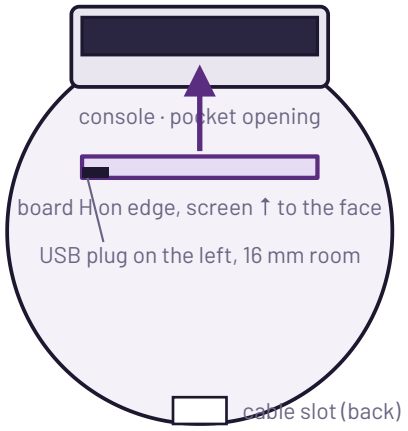
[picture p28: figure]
console · pocket opening; board H on edge, screen ↑ to the face; USB plug on the left, 16 mm room; cable slot (back)

1. Turn plinth C upside down, console toward you. The pocket opening is the rectangular slot in the underside of the console.
2. Unplug the two pigtails from board H so nothing snags. Plug the micro-USB cable into the board. Hold the board on its long edge, screen facing the sloped face, USB plug on the left; the pocket has 16 mm of extra room on that side for the plug.
3. Slide board and plug into the pocket together: light finger pressure, it stops when the glass meets the lip (same fit as step 4). Let the USB cable hang down out of the console.
4. Plug the pigtails back into P1 and CN1; they hang out of the open bottom.
5. Turn the plinth right side up and look at the console: picture centred in the window, even black margin. Turn it back over for wiring.

Loose? A folded strip of masking tape on the back of the board (never the screen) takes up slack. The bottom lid's tongue (step 19) closes the pocket so the board can't drop out.

PAR T 4 · AR ENA AND P L INT H

# Connect the strip and close it up

# 18 Make the three connections (for

# real this time)

5
MIN
Same three joints as the bench test in step 13 (wiring reference on page 8), now with the strip inside the arena and the board inside the plinth.
BOARD PIGTAIL | STRIP WIRE | CARRIES | CONNECTOR
VIN (P1) | Red | 5 V power J1
GND (P1) | White (or black) Ground | J2
IO22 (CN1) | Green | Data | J3
1. Drop top plate L into the ring C: recess up, its notch over the console, the wire slot at the back right. It sits in the ring's rebate flush with the top. Set the arena on the table behind the plinth, flat wall toward the plinth's back.
2. Feed the strip's three wires down through the slot in the plinth's top plate. It's at the back, right of centre, just outside the arena recess, directly under where the wires leave the arena wall.
3. Through the open bottom of the plinth, make the three lever-nut joints per the table. Fold the thin board wires double as before. Close each lever firmly; you'll feel it click.
4. Tug-test all six wire ends.

Red goes to VIN, never to 3V3. 3V3 can't supply the strip and you'll get a dim, flickering beam. Green goes to IO22, not IO27.

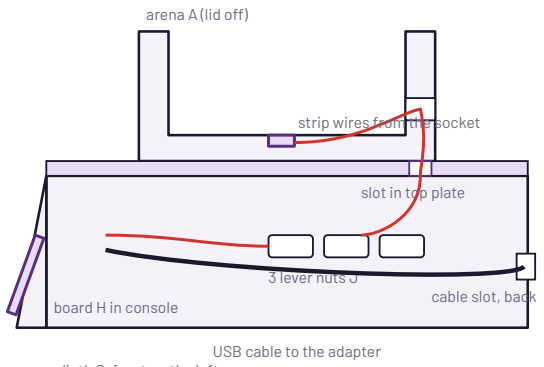
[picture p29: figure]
arena A (lid off); slot in top plate; cable slot, back; 3 lever nuts J; board H in console; USB cable to the adapter; strip wires from the socket

plinth C, front on the left
Strip wires: socket → wire hole → slot in the plinth top → lever nuts. Board USB cable → back slot.

# 19 Route the cable and close the

# plinth

5
MIN
1. Tuck the three connectors into the plinth, toward the back, away from the board.
2. Route the board's USB cable (already plugged in) down through the console, across the inside of the plinth and out the slot at the back (or, if you fitted the optional panel jack, plug its short cable into the board instead and leave the jack's socket facing out).
3. Fit bottom lid D: its tongue goes forward under the console, finger hole toward the back, the USB cable through the notch in the tongue. Press it in evenly until it's flush; the tongue closes the pocket under the board.
4. Set the arena down onto the plate. The recess is cut to its exact D-shaped footprint, so it only fits one way: flat wall at the back. Make sure the strip wires drop into the slot and aren't pinched under the edge.

recess, 2 mm deep

arena A

plinth C · flat back edge of the arena toward the plinth's

PAR T 5 · P O W E R ON AND S E T U P

# Join WiFi and light the beam

20 Power on | 1 MIN
1. Plug the USB cable into adapter K and the adapter into the wall.
2. The screen shows the Kings logo and STARTING, then CONNECTING TO WIFI for up to 20 seconds, then WIFI SETUP.

Use the 2 A adapter, not a laptop port. The beam plus the board
can draw up to about 1 A; a laptop port may brown out and restart
the board mid-animation.

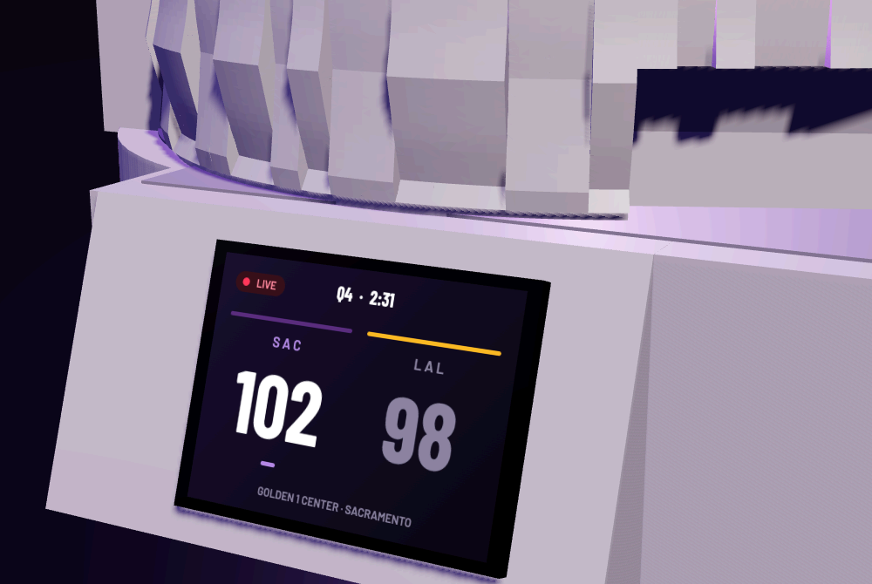
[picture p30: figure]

21 Connect it to your home WiFi from your phone | 3 MIN
1. On your phone, open Settings → WiFi. A new network called KingsBeam-Setup appears (it can take 20 seconds). Join it. There's no password.
2. A setup page pops up on its own, like a hotel login page. If nothing appears within 15 seconds, open the browser and type 192.168.4.1 in the address bar.
3. Tap Configure WiFi. The page lists nearby networks. Tap your home network. If it isn't listed, tap Refresh; the board only sees 2.4 GHz networks, so pick the 2.4 GHz name if your router has separate ones.
4. Type your WiFi password carefully (it's case-sensitive; tap the eye icon to check it) and tap Save.
5. The setup network disappears; your phone reconnects to your normal WiFi by itself. The board's screen shows CONNECTED and then, within about 10 seconds, NEXT GAME with the opponent and tipoff time.

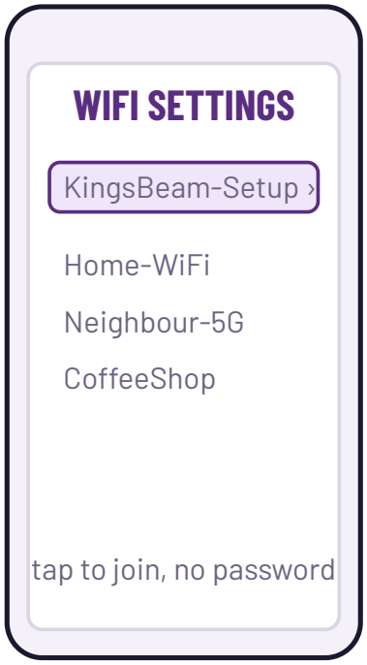
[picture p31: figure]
WIFI SETTINGS; KingsBeam-Setup ›; Home-WiFi; Neighbour-5G; CoffeeShop; tap to join, no password
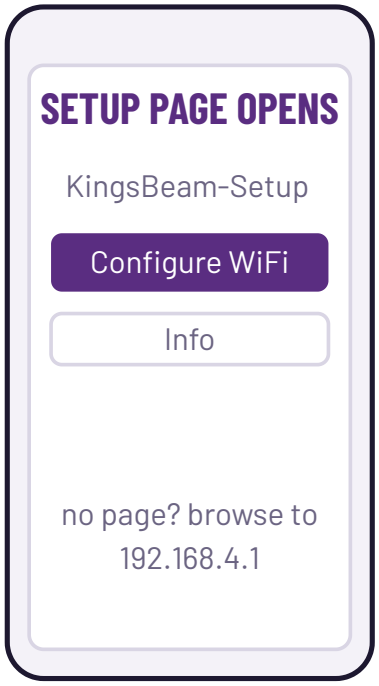
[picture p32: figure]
SETUP PAGE OPENS; KingsBeam-Setup; Configure WiFi; Info; no page? browse to 192.168.4.1
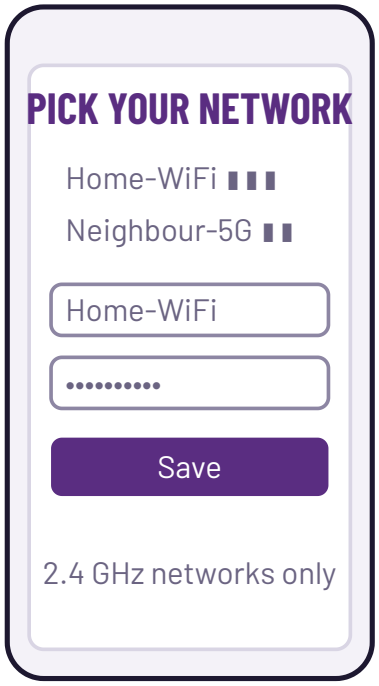
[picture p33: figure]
PICK YOUR NETWORK; Home-WiFi ▮▮▮ Neighbour-5G ▮▮; Home-WiFi; Save; 2.4 GHz networks only

Join the setup network, tap Configure WiFi, choose your home network, type the password, Save.

CHECK The NEXT GAME screen shows the right opponent and a sensible countdown. Time is synced from the internet, so the tipoff shown is already in Pacific time.

DAY TO DAY

# Using it

## What the screen shows

NEXT GAME | Opponent logo, VS (home) or @ (away), tipoff in Pacific time, countdown pill. Refreshes every 10 minutes; every 30 seconds in the last 20 minutes before tipoff.
LIVE | Score, quarter and clock, refreshed every 20 seconds. Leader in white, trailer in grey with a marker under the leader. Halftime, end of quarter and overtime are labelled. The beam pulses softly.
FINAL, KINGS WIN | Score, "LIGHT THE BEAM", and the beam rises and holds.
FINAL, LOSS | Score and "NEXT TIME". The beam stays off unless you tap it.

NO GAME SCHEDULED Off-season: the Kings logo and "NO
| GAME SCHEDULED".
OFFLINE | A small OFFLINE badge in the corner. The last good screen stays; it retries every minute.

## Touch

TAP | Beam on / off, in any state.
HOLD 1 S | Cycle beam brightness: low → medium → full.

## Automatic behaviour

AFTER A WIN | The beam stays lit up to 12 hours, until you tap it off, or until the next game shows up on the schedule.
AT NIGHT | Screen dims 11 pm–7 am, and whenever the room is dark (the board has a light sensor).
POWER LOSS | Reboots into the current state in ~15 seconds; WiFi is remembered.
NEW WIFI | If it can't find the saved network for 20 seconds after boot, KingsBeam-Setup opens again. Repeat step 21.

## Care

Dust with a dry cloth. Keep out of direct sun and off radiators: PLA softens around 55 °C and the tube is thin. The lid lifts off to reach the beam; the bottom lid pulls off (finger hole) to reach the board. Unplug before opening.

I F S O M E T H ING ' S O F F

# Troubleshooting

SYMPTOM | TRY
Screen stays dark | Use the 2 A adapter, not a laptop. Try the board's other USB port if it has two. Check the
cable is a data cable if you're flashing.
Colours inverted or milky | You have the other board variant. In firmware/platformio.ini , comment out
ILI9341_2_DRIVER and enable the ST7789_DRIVER + TFT_INVERSION_ON lines
Picture upside down | In firmware/src/ui.cpp change LV_DISPLAY_ROTATION_90 to _270 ; reflash.
Screen off-centre in the window | Adjust screen_ofs_x / screen_ofs_y in models/plinth.scad by the offset in
mm, make , reprint the console test part.
Beam never lights, even on tap | Unplug. Check red → VIN (not 3V3), green → IO22 (not IO27), white → GND. Check the
strip's arrows point away from the wired end. Check each lever nut grips (tug test).

Only LED 1 lights / random colours Data signal is marginal. Shorten the green lead to the minimum, or add the 74AHCT125 level shifter between IO22 and the strip's green wire.

Beam dim or flickers with the screen Weak power. Use a 2 A adapter and a short USB cable. Step brightness down (hold 1 s) if it's a weak charger you can't change.

Beam leans | Socket not flat or off-centre: lift the lid, reheat the glue, reseat (step 14).
OFFLINE badge won't clear | ESPN unreachable from your network. It retries every minute. Check other devices have
internet; reboot the board. If it persists for days, ESPN may have changed its edge rules; check python3 tools/espn_probe.py on your Mac.
Countdown wrong by hours | Clock not synced yet; wait a minute after connecting. If it stays wrong, your router
blocks NTP (UDP 123).
Taps ignored | Press firmly with a fingertip in the middle of the screen; it's a resistive panel. Lower
Z_THRESHOLD in firmware/src/touch.cpp if it never registers.
Setup network never appears | Power-cycle the board. It only opens the portal when it can't connect; if it already knows
a WiFi and that WiFi is up, there's nothing to set up.

## Specifications

FOOTPRINT | 228 × 246 mm (plinth with console)
HEIGHT | ≈ 310 mm to the beam tip
POWER | 5 V USB, ≈ 0.7 A with the beam lit, 1.1 A
worst case, 0.3 A idle
NETWORK | 2.4 GHz WiFi, outbound HTTPS and NTP
only
DATA | ESPN public scores; no account,
nothing stored
BOARD | ESP32-2432S028R, 2.8" 320 × 240
resistive touch
BEAM | 14 × WS2812B in a 12 × 250 mm white
PLA tube

## Safety

Low-voltage USB only; never connect to anything but a 5 V USB adapter. Indoor use. Unplug before opening the plinth or touching the wiring. The beam tube is thin-walled and not a toy. Printed PLA parts are not food-safe and should be kept away from heat.

## Files

Everything referenced here lives in the project repo: firmware/ (build and flash), models/ (OpenSCAD and STL exports), docs/bom.md (parts with links), tools/ (helper scripts).

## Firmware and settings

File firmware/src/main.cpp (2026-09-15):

// Kings "Light the Beam" scoreboard — main loop.
//
//   boot → WiFi (captive portal on first run) → NTP → poll ESPN → drive screen + beam
//
// Build with -DDEMO_MODE to skip WiFi and cycle NEXT → LIVE → FINAL from canned data.
#include <Arduino.h>
#include <WiFi.h>
#include <Preferences.h>
#include <time.h>
#include "config.h"
#include "game_state.h"
#include "beam_policy.h"
#include "kings_api.h"
#include "ui.h"
#include "winprob_train.h"
#include "beam.h"
#include "touch.h"

// TLS handshakes and LVGL's software renderer both run on the Arduino loop task; the default
// 8 KB stack is the usual overflow on CYD + LVGL 9 builds.
SET_LOOP_TASK_STACK_SIZE(16 * 1024);

#ifndef DEMO_MODE
#include <WiFiManager.h>
static WiFiManager wm;
static bool portalActive = false;
static uint32_t noWifiSince = 0;              // millis() of the first consecutive NoWifi result
static const uint32_t PORTAL_TIMEOUT_S = 180;  // portal closes itself after this
static const uint32_t REOPEN_PORTAL_MS = 10UL * 60UL * 1000UL;   // no WiFi this long → offer setup again
#endif

static Preferences prefs;
static GameState game;
static bool haveGame = false;
static bool offline = false;
static uint32_t nextPollAt = 0;
static uint32_t beamLitAt = 0;
static char celebratedEvent[16] = "";
static bool timeSynced = false;

static int64_t nowEpoch() {
  time_t t = time(nullptr);
  return t > 1600000000 ? (int64_t)t : 0;   // 0 = clock not synced yet
}

// ---- game state → screen + beam --------------------------------------------------
static void applyGame(const GameState& gs) {
  int64_t now = nowEpoch();
  BeamDecision d = beamPolicy(beam_mode(), game, gs, celebratedEvent, now, BEAM_HOLD_HOURS);
  game = gs;
  haveGame = true;

  if (d.celebrate) {
    strncpy(celebratedEvent, gs.eventId, sizeof celebratedEvent - 1);
    prefs.putString("celeb", celebratedEvent);   // survives a reboot: no encore after a power blip
    beamLitAt = millis();
    log_i("KINGS WIN %d-%d — light the beam", gs.us.score, gs.them.score);
  }
  if (d.mode != beam_mode()) beam_set_mode(d.mode);

  ui_show_game(game, beam_is_lit());
  nextPollAt = millis() + pollIntervalMs(game, now, POLL_PRE_MS, POLL_PRE_SOON_MS, POLL_LIVE_MS, POLL_POST_MS, PRE_SOON_WINDOW_S);
}

static void poll() {
#ifndef DEMO_MODE
  GameState gs;
  int code = 0;
  if (!haveGame) { ui_show_boot("FETCHING SCHEDULE"); ui_flush(); }
  kings::FetchResult r = kings::fetch(gs, &code);
  log_i("fetch: %s (http %d) heap %u", kings::fetchResultName(r), code, ESP.getFreeHeap());
  if (r == kings::FetchResult::Ok) {
    offline = false;
    noWifiSince = 0;
    applyGame(gs);
  } else {
    offline = true;
    if (r == kings::FetchResult::NoWifi) { if (!noWifiSince) noWifiSince = millis(); }
    else noWifiSince = 0;
    if (!haveGame) {
      ui_show_boot(r == kings::FetchResult::NoWifi ? "NO WIFI \xC2\xB7 RETRYING" : "ESPN UNREACHABLE \xC2\xB7 RETRYING");
      ui_flush();
    }
    nextPollAt = millis() + POLL_ERROR_MS;
  }
  ui_set_offline(offline);
#endif
}

// ---- touch -------------------------------------------------------------------
static void onTap() {
  beam_toggle();
  beamLitAt = millis();
  if (haveGame) ui_show_game(game, beam_is_lit());
}
static void onLongPress() { beam_cycle_brightness(); }

// ---- night dimming -----------------------------------------------------------
static void nightTick() {
  static uint32_t last = 0;
  if (millis() - last < 30000) return;
  last = millis();
  if (!nowEpoch()) return;   // clock not set yet
  time_t now = time(nullptr);
  struct tm lt;
  localtime_r(&now, &lt);
  bool night = (NIGHT_START_HOUR > NIGHT_END_HOUR)
                   ? (lt.tm_hour >= NIGHT_START_HOUR || lt.tm_hour < NIGHT_END_HOUR)
                   : (lt.tm_hour >= NIGHT_START_HOUR && lt.tm_hour < NIGHT_END_HOUR);
  // the CYD's LDR reads higher in the dark; blend it in so a dark room also dims
  int ldr = analogRead(LDR_PIN);
  bool darkRoom = ldr > 3000;
  ui_set_backlight(night || darkRoom ? BL_NIGHT : BL_DAY);
}

// ---- demo mode ---------------------------------------------------------------
#ifdef DEMO_MODE
static void demoTick() {
  static uint32_t phaseStart = 0;
  static int phase = -1;
  static GameState d;
  uint32_t now = millis();
  int wanted = ((now / 9000) % 3);
  if (wanted != phase) {
    phase = wanted;
    phaseStart = now;
    d = GameState{};
    strcpy(d.eventId, phase == 0 ? "demo-pre" : "demo-game");
    strcpy(d.us.abbr, TEAM_ABBR); strcpy(d.us.name, "Kings"); d.us.home = true;
    strcpy(d.them.abbr, "LAL"); strcpy(d.them.name, "Lakers");
    strcpy(d.dateUtc, "2026-10-06T02:00Z"); d.tipoffEpoch = 1791252000LL;
    strcpy(d.shortName, "LAL @ SAC");
    d.valid = true;
    if (phase == 0) { d.status = GameStatus::Pre; strcpy(d.detail, "10/5 - 7:00 PM"); }
    if (phase == 1) { d.status = GameStatus::Live; d.us.score = 98; d.them.score = 96; d.period = 4; strcpy(d.clock, "2:31"); strcpy(d.detail, "2:31 - 4th"); }
    if (phase == 2) { d.status = GameStatus::Post; d.completed = true; d.us.score = 112; d.them.score = 108; d.us.winner = true; strcpy(d.detail, "Final"); celebratedEvent[0] = 0; }
    applyGame(d);
  }
  if (phase == 1 && now - phaseStart > 3000 && d.us.score == 98) {   // a 3-pointer lands
    d.us.score = 101; strcpy(d.clock, "2:04");
    applyGame(d);
  }
}
#endif

// ---- WiFi --------------------------------------------------------------------
#ifndef DEMO_MODE
static void onWifiUp(const char* how) {
  portalActive = false;
  noWifiSince = 0;
  log_i("WiFi connected (%s): %s", how, WiFi.localIP().toString().c_str());
  configTzTime(TZ_POSIX, NTP_SERVER);
  ui_show_boot("CONNECTED");
  ui_flush();
  nextPollAt = millis() + 1000;
}

static void openPortal() {
  portalActive = true;
  ui_show_wifi_setup(WIFI_PORTAL_SSID);
  ui_flush();
  wm.startConfigPortal(WIFI_PORTAL_SSID);   // non-blocking; loop() drives wm.process()
}
#endif

// ---- arduino -----------------------------------------------------------------
// The binned 2024-25 play-by-play table linked into the image (platformio.ini embed_files).
extern const uint8_t winprobTableStart[] asm("_binary_data_winprob_train_bin_start");
extern const uint8_t winprobTableEnd[]   asm("_binary_data_winprob_train_bin_end");
// Coefficients in use: refit on boot from the table, else the compiled Python fit.
kings::WinProbCoef winprobCoef = kings::WINPROB_COMPILED;

static void trainWinProbOnBoot() {
  kings::WinProbFit fit;
  uint32_t t0 = millis();
  bool ok = kings::winProbTrain(winprobTableStart, winprobTableEnd - winprobTableStart, WINPROB_EPS, fit);
  uint32_t ms = millis() - t0;
  if (!ok) { log_w("win-prob refit failed, using compiled coefficients"); return; }
  winprobCoef = fit.coef;
  log_i("win-prob refit: %u plays in %u cells, %d iterations, %u ms: a=%.5f b_ms=%.5f b_s=%.5f b_m=%.5f (compiled %.5f %.5f %.5f %.5f)",
        fit.plays, fit.cells, fit.iterations, ms, fit.coef.a, fit.coef.b_ms, fit.coef.b_s, fit.coef.b_m,
        WINPROB_A, WINPROB_B_MS, WINPROB_B_S, WINPROB_B_M);
  char msg[48];
  snprintf(msg, sizeof msg, "TRAINED ON %u PLAYS IN %u MS", fit.plays, ms);
  ui_show_boot(msg);
  ui_flush();
  delay(1500);   // long enough to read; the flex is the point
}

void setup() {
  Serial.begin(115200);
  delay(100);
  log_i("Kings beam boot, heap %u", ESP.getFreeHeap());

  prefs.begin("kingsbeam", false);
  prefs.getString("celeb", celebratedEvent, sizeof celebratedEvent);

  ui_init();
  ui_show_boot("STARTING");
  ui_flush();
  trainWinProbOnBoot();
  beam_init();
  touch_init();
  touch_set_tap(onTap);
  touch_set_long_press(onLongPress);
  setenv("TZ", TZ_POSIX, 1);
  tzset();

#ifdef DEMO_MODE
  log_i("DEMO MODE: no WiFi");
  // pretend the clock is set so countdowns render
  struct timeval tv = {.tv_sec = 1791252000 - 2 * 86400 - 4 * 3600, .tv_usec = 0};
  settimeofday(&tv, nullptr);
#else
  WiFi.mode(WIFI_STA);
  wm.setConfigPortalBlocking(false);
  wm.setConnectTimeout(20);
  // The portal closes itself after 3 minutes. If credentials are saved (a router that was
  // still booting after a power cut), restart and try them again instead of sitting on the
  // setup screen forever.
  wm.setConfigPortalTimeout(PORTAL_TIMEOUT_S);
  wm.setConfigPortalTimeoutCallback([]() {
    if (wm.getWiFiIsSaved()) { log_i("portal timed out with saved creds: restarting"); ESP.restart(); }
  });
  wm.setAPCallback([](WiFiManager*) {
    portalActive = true;
    ui_show_wifi_setup(WIFI_PORTAL_SSID);
    ui_flush();
  });
  ui_show_boot("CONNECTING TO WIFI");
  ui_flush();
  if (wm.autoConnect(WIFI_PORTAL_SSID)) onWifiUp("boot");
  nextPollAt = millis() + 1500;
#endif
}

void loop() {
  time_t now = time(nullptr);
  ui_tick(now);
  beam_tick();
  touch_tick();
  nightTick();

#ifdef DEMO_MODE
  demoTick();
#else
  if (portalActive) {
    wm.process();
    if (WiFi.status() == WL_CONNECTED) onWifiUp("portal");
    else if (!wm.getConfigPortalActive()) {   // closed by its timeout without saved creds
      portalActive = false;
      ui_show_boot("NO WIFI \xC2\xB7 RETRYING");
      ui_flush();
      nextPollAt = millis() + POLL_ERROR_MS;
    }
    return;
  }
  if (!timeSynced && nowEpoch()) {
    timeSynced = true;
    log_i("time synced");
    if (haveGame) ui_show_game(game, beam_is_lit());
  }
  if ((int32_t)(millis() - nextPollAt) >= 0) {
    poll();
  }
  // Saved network gone for good (moved house, new router): offer the setup portal again.
  if (noWifiSince && millis() - noWifiSince > REOPEN_PORTAL_MS) {
    log_i("no WiFi for %lu s: reopening the setup portal", (unsigned long)((millis() - noWifiSince) / 1000));
    noWifiSince = 0;
    openPortal();
    return;
  }
#endif

  // beam hold timeout after a win (or a manual light)
  if (beam_is_lit() && beamLitAt && millis() - beamLitAt > (uint32_t)BEAM_HOLD_HOURS * 3600000UL) {
    beam_set_mode(BeamMode::Off);
    beamLitAt = 0;
    if (haveGame) ui_show_game(game, false);
  }
  delay(5);
}

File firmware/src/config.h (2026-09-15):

// Kings "Light the Beam" scoreboard — build-time configuration
#pragma once

// ---- Team --------------------------------------------------------------------
#define TEAM_ABBR        "SAC"
#define TEAM_SLUG        "sac"          // ESPN team slug in the URL
#define ESPN_URL         "https://site.api.espn.com/apis/site/v2/sports/basketball/nba/teams/" TEAM_SLUG
// ESPN's edge (Akamai) returns 403 to browser-looking user agents from non-browser clients.
// The stock ESP32 HTTPClient UA passes, so we send that and never spoof a browser.
#define ESPN_USER_AGENT  "ESP32HTTPClient"

// ---- Time --------------------------------------------------------------------
#define TZ_POSIX         "PST8PDT,M3.2.0,M11.1.0"   // America/Los_Angeles
#define NTP_SERVER       "pool.ntp.org"

// ---- Poll cadence (ms) -------------------------------------------------------
#define POLL_PRE_MS          (10UL * 60UL * 1000UL)  // next game far away
#define POLL_PRE_SOON_MS     (30UL * 1000UL)         // within PRE_SOON_WINDOW of tipoff
#define POLL_LIVE_MS         (20UL * 1000UL)
#define POLL_POST_MS         (5UL * 60UL * 1000UL)
#define POLL_ERROR_MS        (60UL * 1000UL)
#define PRE_SOON_WINDOW_S    (20L * 60L)             // seconds before tipoff to speed up
#define HTTP_TIMEOUT_MS      15000

// ---- Beam (WS2812B strip) ----------------------------------------------------
#define BEAM_PIN             22      // CYD connector CN1: GND, IO22, IO27, 3V3
#define BEAM_NUM_LEDS        14      // 14 x 16.67 mm = 233 mm of strip inside the 250 mm tube
#define BEAM_MAX_BRIGHTNESS  128     // 0-255; caps current so a 2 A USB charger is plenty
#define BEAM_HOLD_HOURS      12      // stay lit this long after a win (or until tapped off)
#define BEAM_PURPLE          0x5A2D81
#define BEAM_PURPLE_BRIGHT   0x8A4DD0

// ---- Display / touch (CYD) ---------------------------------------------------
#define SCREEN_W             320
#define SCREEN_H             240
#define TFT_BL_PIN           21
#define TOUCH_CLK            25
#define TOUCH_MOSI           32
#define TOUCH_MISO           39
#define TOUCH_CS             33
#define TOUCH_IRQ            36
#define LDR_PIN              34      // onboard light sensor (higher ADC = darker)

// ---- Night dimming -----------------------------------------------------------
#define NIGHT_START_HOUR     23
#define NIGHT_END_HOUR       7
#define BL_DAY               255
#define BL_NIGHT             25

// ---- WiFi portal -------------------------------------------------------------
#define WIFI_PORTAL_SSID     "KingsBeam-Setup"

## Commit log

2026-09-15 Scaffold repo, ESPN probe and test fixtures
    - tools/espn_probe.py: fetch ESPN team endpoint, print parsed game state,
    save raw fixture. Found that ESPN's edge 403s browser-like user agents
    from non-browser clients; stock library UAs pass.
    - tools/make_fixtures.py: build post_win / post_loss / live fixtures from
    real completed Kings games via the scoreboard endpoint.
    - README with project overview and layout.
2026-09-15 Firmware: ESPN parser with native tests, PlatformIO config, fonts and team data
    - kings_parse.h: ArduinoJson filtered parse of the team endpoint into GameState.
    Needs NestingLimit(24) (ESPN nests deeper than the default 10) and an explicit
    check for the team object, since a filtered parse reports Ok on non-JSON input.
    - 7 Unity tests over the captured fixtures pass on the native env.
    - platformio.ini: cyd / cyd_demo / native envs, TFT_eSPI flags for the CYD.
    - Barlow Condensed TTFs (OFL) and ESPN team list for the generators.
    [config.h]
2026-09-15 Firmware builds: LVGL scoreboard UI, beam animations, touch, WiFi portal, demo mode
    - ui.cpp: NEXT GAME / LIVE / FINAL / setup / boot screens in LVGL 9 with
    Barlow Condensed fonts (generated by tools/make_fonts.py, no node needed)
    and 30 team logos as RGB565A8 images (tools/make_logos.py).
    - beam.cpp: FastLED Off / Pulse / Rise / Hold; rise-from-the-base win animation.
    - touch.cpp: direct XPT2046 SPI pressure read for tap / long-press.
    - main.cpp: WiFiManager captive portal, NTP, poll scheduler by game state,
    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
    [beam_tube.scad, plinth.scad, strip_holder.scad]
2026-09-15 docs: bill of materials with links, prices and Bayview local pickup
2026-09-15 README: build, flash, print and dev instructions; status
2026-09-15 docs: rendered views (three.js, headless Chrome) and a product-style assembly guide
    - docs/render/scene.html: parametric scene of the piece with named views
    (hero, exploded, cutaway, beam, strip, wiring, lid, plinth_top, screen);
    tools/render_views.sh renders them with software WebGL.
    - Overview cover and exploded view now use the renders.
    - docs/assembly.html -> kings-beam-assembly.pdf: 9-page guide: in the box,
    8 numbered steps with renders, using it, troubleshooting, printing, specs.
2026-09-15 Renders match the real arena; build guide rewritten in detail
    - scene.html: arena rebuilt from the Printables model's shield footprint with
    facade fins, dark glass storeys, roof overhang, lid with roof-seam grid and
    rooftop plant; screen recessed into a flat facet on the plinth.
    - assembly.html/pdf: 13 pages, 22 numbered steps in five parts (print, flash,
    beam, arena + plinth, setup) with times, checks and warnings, plus using it,
    troubleshooting, specs.
2026-09-15 Build guide: ten assembly diagrams and a screen-mount page
    Line diagrams for the strip cut, spine into tube, board sockets, lever nuts,
    socket and tube, lid, wire routing, arena seating and the phone setup, plus a
    page with front / side-section / bottom views of how the display board mounts
    in the plinth pocket. Wiring reference gets its own page. 15 pages.
2026-09-15 Screen moves to a sloped console; arena facade matches Golden 1 Center
    - plinth.scad: console wedge on the front, face leaning back 20 deg, pocket
    open at the bottom, lid gets a tongue with the retaining bump; test part is
    the console alone. Fixes the recessed-tilt design where the top plate hid
    the top third of the screen from desk viewing angles.
    - scene.html: console wedge; arena now has a glass lower level with mullions,
    the five hangar doors on the plaza edge, sawtooth-faceted metal cladding,
    and a solar array on the roof instead of the invented fins.
    - Build guide: screen-mount page redrawn for the console; steps 4, 17, 19
    updated; renders regenerated; both PDFs rebuilt.
    C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
    [plinth.scad]
2026-09-15 Real arena geometry: measured STL drives the plinth recess, wire slot, renders and guide
    - tools/measure_arena.py slices the downloaded 220 mm base: 205.8 x 208.2 mm
    D-shaped footprint, ~2 mm solid floor, 125 mm octagonal well, built-in wire
    channel exiting the flat wall at the back right (z 3-10), lid seat at 49.5.
    Writes models/arena_outline.scad.
    - plinth.scad: recess cut to the measured outline (rotated flat-edge-back),
    wire slot under the channel exit, height 56 so the screen has a frame.
    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
    [arena_outline.scad, plinth.scad]
2026-09-15 Hero render: frame the whole plinth on the covers
2026-09-15 Render: USB cable droops to the table instead of a straight rod
2026-09-15 README with renders, shopping list with one-click Amazon cart, CI workflow, validator
    - README rewritten around the renders and the three screens; documents table.
    - docs/shopping-list.html (+PDF): four-item Amazon add-to-cart link, filament,
    free downloads, optional parts, SF local pickup.
    - .github/workflows/ci.yml: native tests, both ESP32 builds, generator
    reproducibility (fonts, logos), OpenSCAD export of every part.
    - tools/validate.sh runs all checks locally; tools/check_fixtures.py checks the
    captured fixtures with the Python reference parser; make_logos.py --offline.
    - Removed the superseded placement-options page.
2026-09-15 Apply the three review reports: firmware fixes, plinth redesign, tests, doc corrections
    Firmware (13 findings): TFT on HSPI so touch and display no longer share
    VSPI; WiFi portal times out (restart with saved creds) and reopens after
    10 min without WiFi; postponed games no longer render as a 0-0 loss; no
    screen wipe on every refresh (score animations work again); celebration
    persisted in NVS so a reboot doesn't replay the win; 16 KB loop stack;
    Accept-Encoding identity; boot screens flushed before blocking calls; touch
    release debounce; aligned draw buffer; Live->None turns the beam off; score
    objects and numeric ids parse; stale-tipoff polling bounded; LV_CONF_PATH
    dropped; strip only writt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
    [arena_outline.scad, beam_tube.scad, plinth.scad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]
2026-09-15 Validator reads ASCII STL exports; renders and PDFs regenerated for the new plinth
2026-09-15 Win-probability model with a C++ test bench
    Four-coefficient logistic model of home win probability from score, clock
    and period, fitted by tools/train_winprob.py (pure Python) on 2024-25 and
    held out on 2025-26 against ESPN's own in-game numbers. The bench runs
    in the firmware toolchain: winprob.h is the ESP32 code path, and the
    native test checks parity with the trainer, function shape, and a replay
    of all 641,199 held-out plays from a 5-byte-per-play fixture, asserting
    Brier, fourth-quarter and calibration thresholds. docs/winprob.md has
    the report.
2026-09-15 On-device trainer for the win-probability model
    The training plays are binned to 35,221 (margin, 5 s) cells with win/loss
    counts, a 247 KB table embedded in the firmware image. winprob_train.h is
    the same weighted Newton-Raphson fit as the Python script, header-only;
    the board refits on boot and shows the play count and time on the splash.
    A native test refits from the table on the host and matches the Python
    coefficients to 1e-6, and recovers known coefficients from synthetic data.
2026-09-15 Document accuracy by phase, Kings-only calibration and open evaluation questions
    The report now explains why calibration, not accuracy, is the test of the
    pill, tabulates accuracy by game phase against ESPN and the always-home
    baseline, and restricts calibration to the team the pill shows. That last
    table finds the model overstated the Kings' chances in toss-up situations
    last season (a 22-win team vs. the league-average prior), which promotes
    the team-strength prior to the first follow-up.
